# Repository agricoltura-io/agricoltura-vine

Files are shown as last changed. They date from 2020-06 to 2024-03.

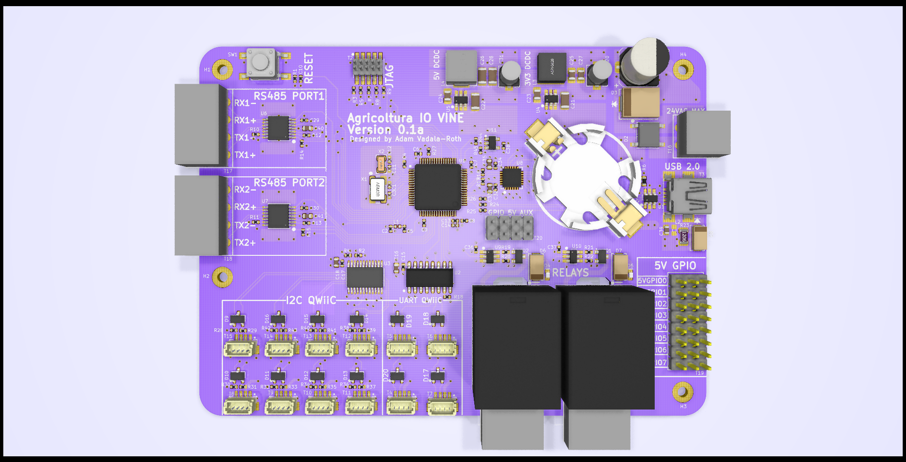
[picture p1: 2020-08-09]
PCB/agricoltura-vine/agricoltura-vineRAY.png

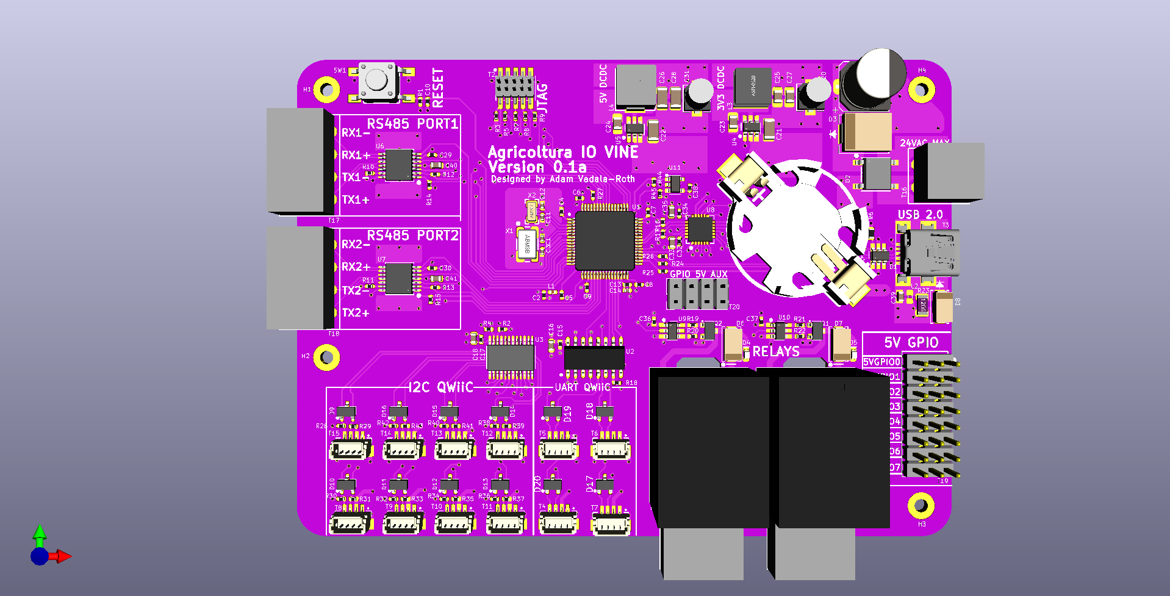
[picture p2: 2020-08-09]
PCB/agricoltura-vine/agricoltura-vine.png

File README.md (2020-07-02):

# agricoltura-vine
daisy chainable interface for a variety of sensors for various agriculture applications, this is Agricoltura-io's wired sense and control platform.

Quick Specs:
- ST Microelectronics STM32F446RET6 ARM Cortex M4F 180MHZ MCU
- 5V Tolerant Analog Inputs
- 8x I2C interfaces
- 4x UART interface (via mux)
- 8x 5V digital IO ports
- 2x G5LE-14 DC5 SPDT Relays
- USB 2.0 connectivity
- RS485 port
- 24VAC power input
- 2A 3.3V DCDC Regulator, for supporting lots of sensors
- 2A 5V DCDC Regulator, for 5V IO and other devices

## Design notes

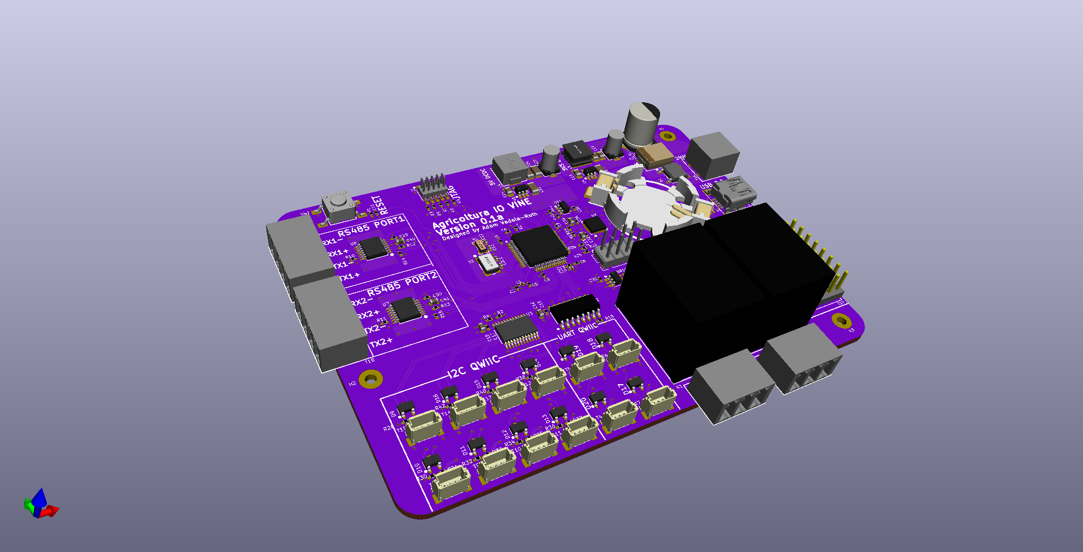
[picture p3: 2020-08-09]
PCB/agricoltura-vine/agricoltura-vineRAYAngle.png

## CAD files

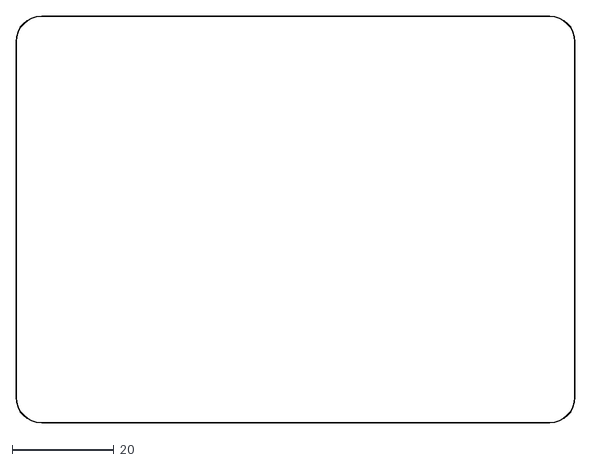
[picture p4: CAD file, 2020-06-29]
PCB/agricoltura-vine/Vine_Ivy_BRD_Shape.dxf
110.0 x 80.0

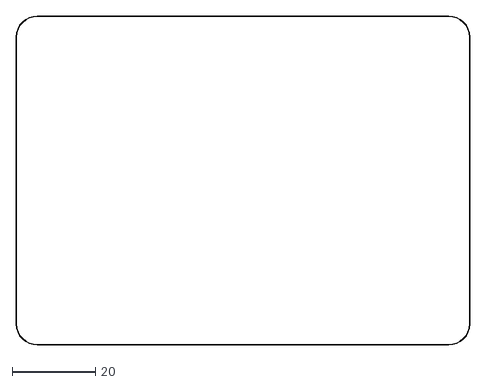
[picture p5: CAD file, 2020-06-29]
PCB/agricoltura-vine/Vine_Ivy_BRD_Margin.dxf
109.0 x 79.0

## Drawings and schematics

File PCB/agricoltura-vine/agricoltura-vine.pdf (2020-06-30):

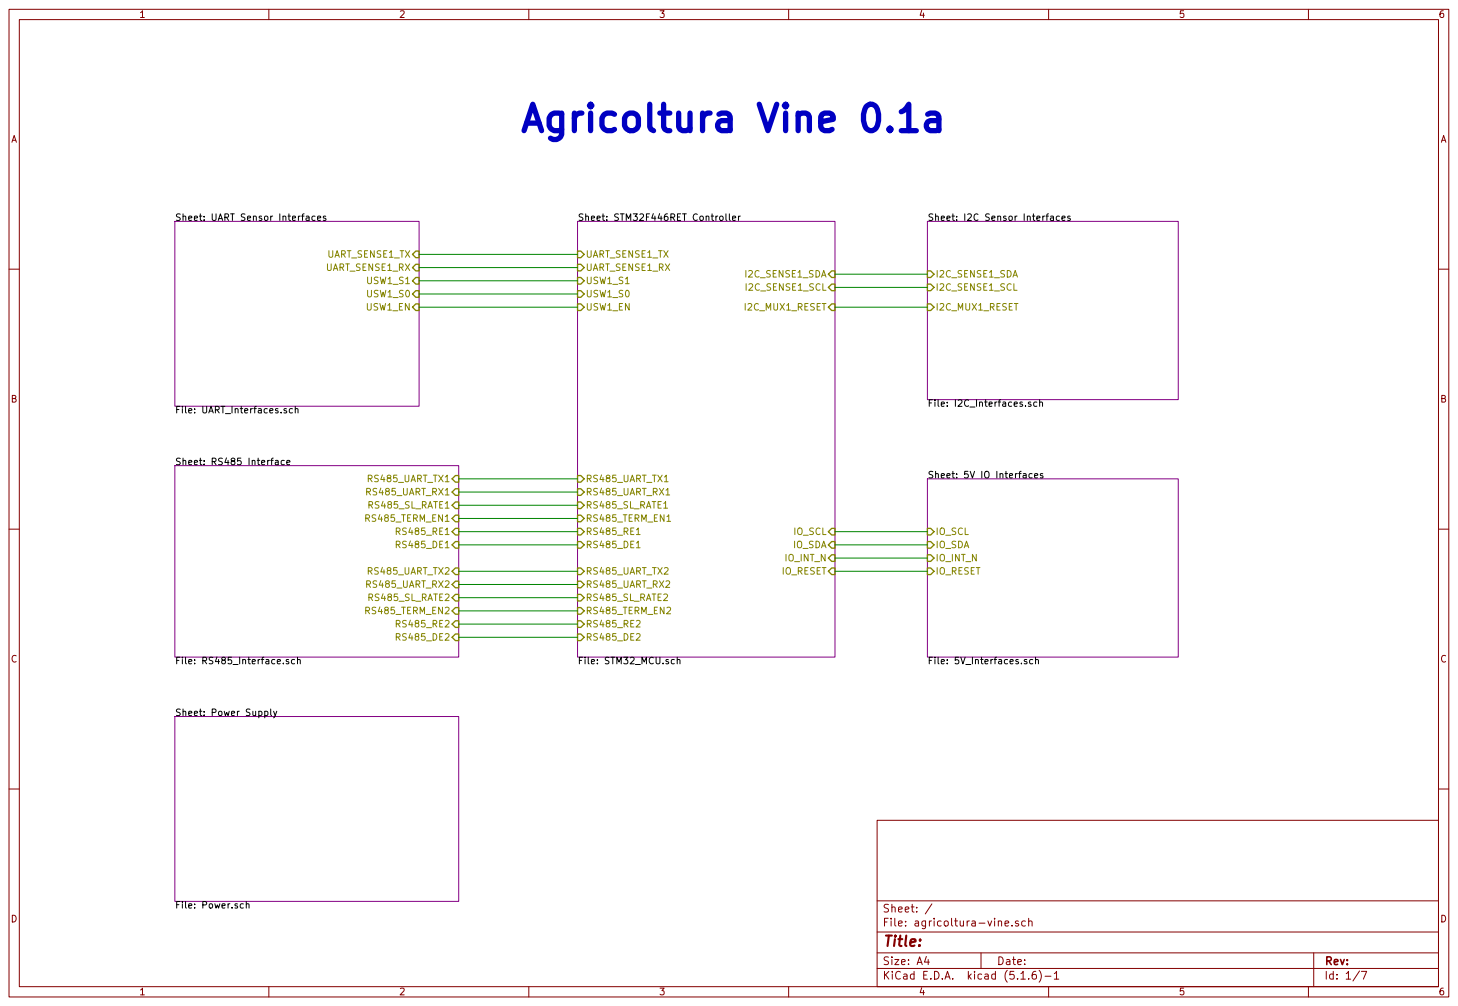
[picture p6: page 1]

IO_RESET Sheet: STM32F446RET Controller File: STM32_MCU.sch UART_SENSE1_TX RS485_UART_TX1 RS485_UART_RX1 RS485_UART_TX2 RS485_UART_RX2

Sheet: I2C Sensor Interfaces File: I2C_Interfaces.sch

Sheet: 5V IO Interfaces File: 5V_Interfaces.sch

File: agricoltura-vine.sch Sheet: /
Id: 1/7 Title:

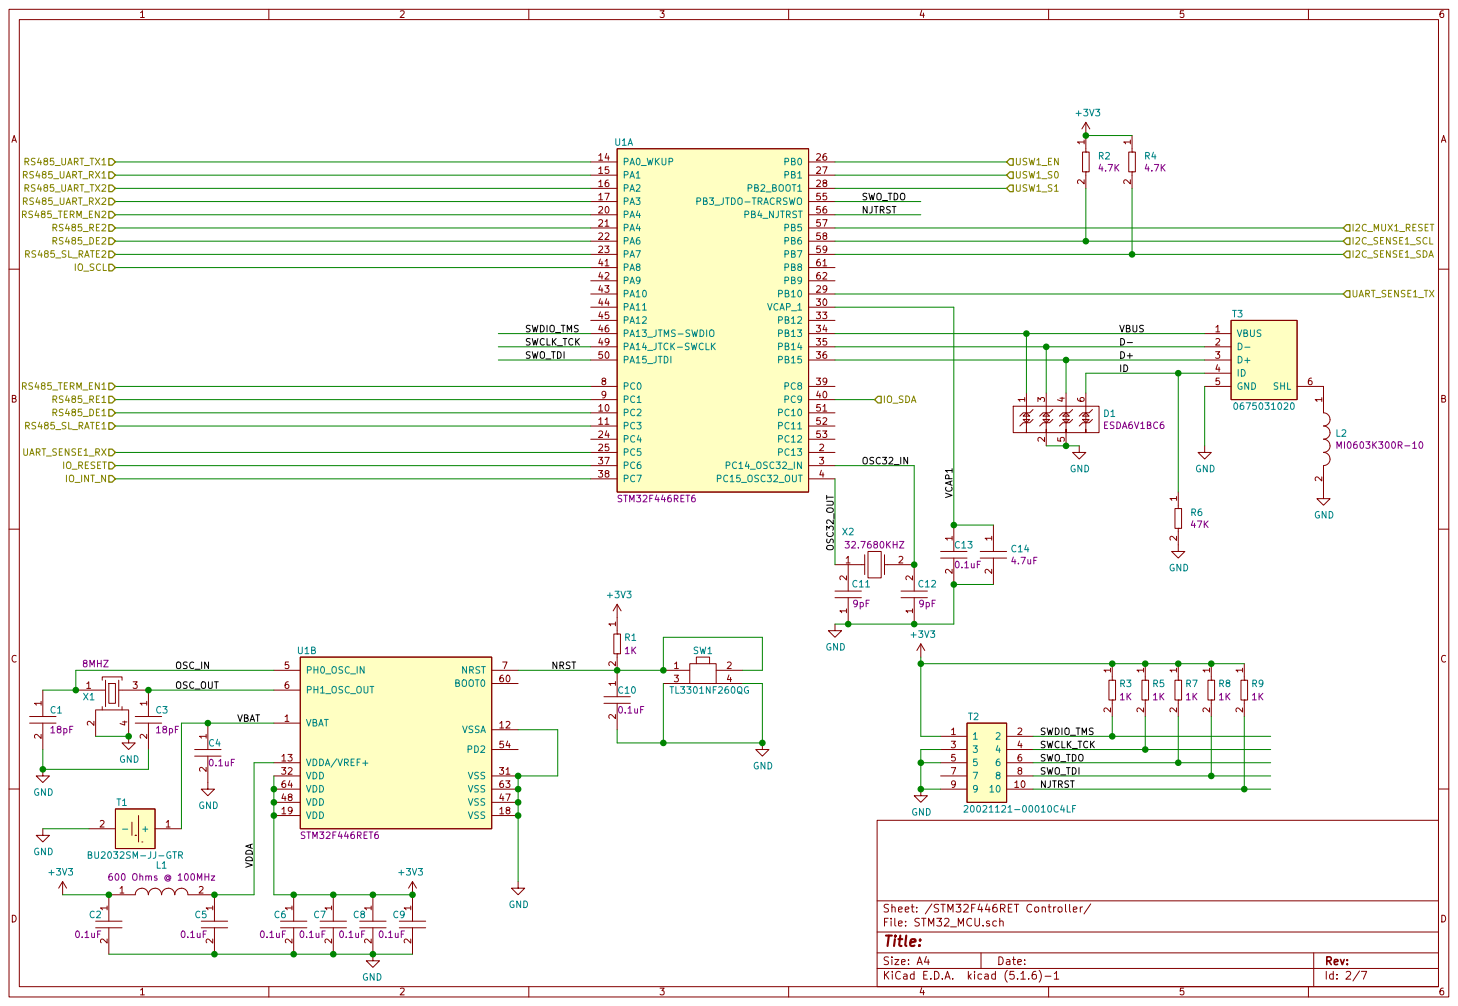
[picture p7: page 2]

File: STM32_MCU.sch Sheet: /STM32F446RET Controller/
Id: 2/7 Title:

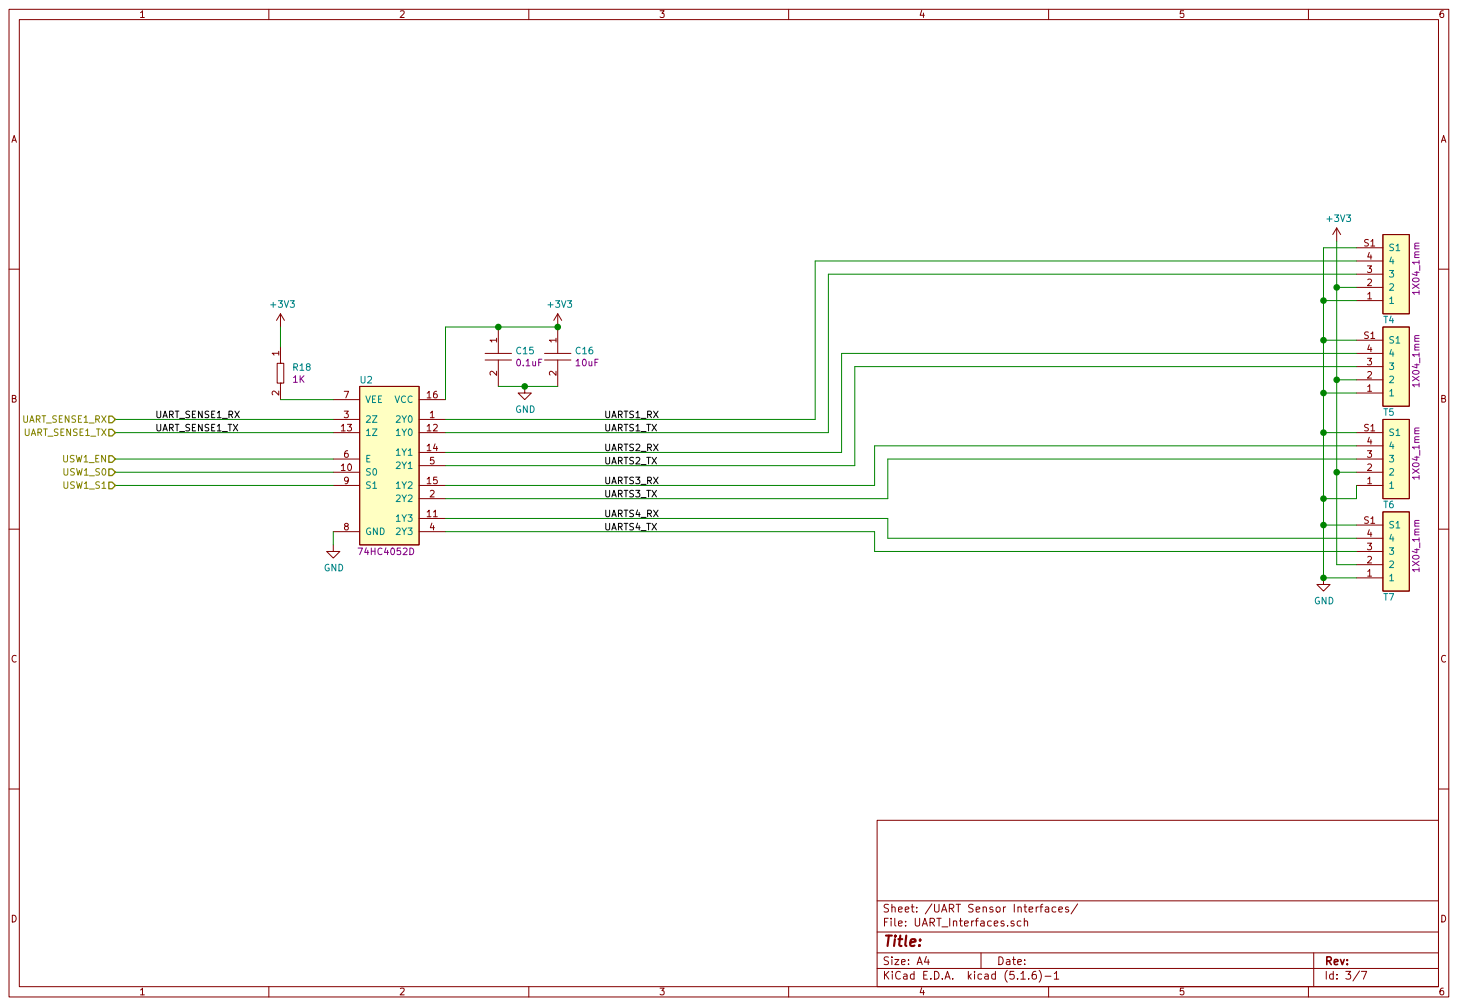
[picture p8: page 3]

File: UART_Interfaces.sch Sheet: /UART Sensor Interfaces/
Id: 3/7 Title:

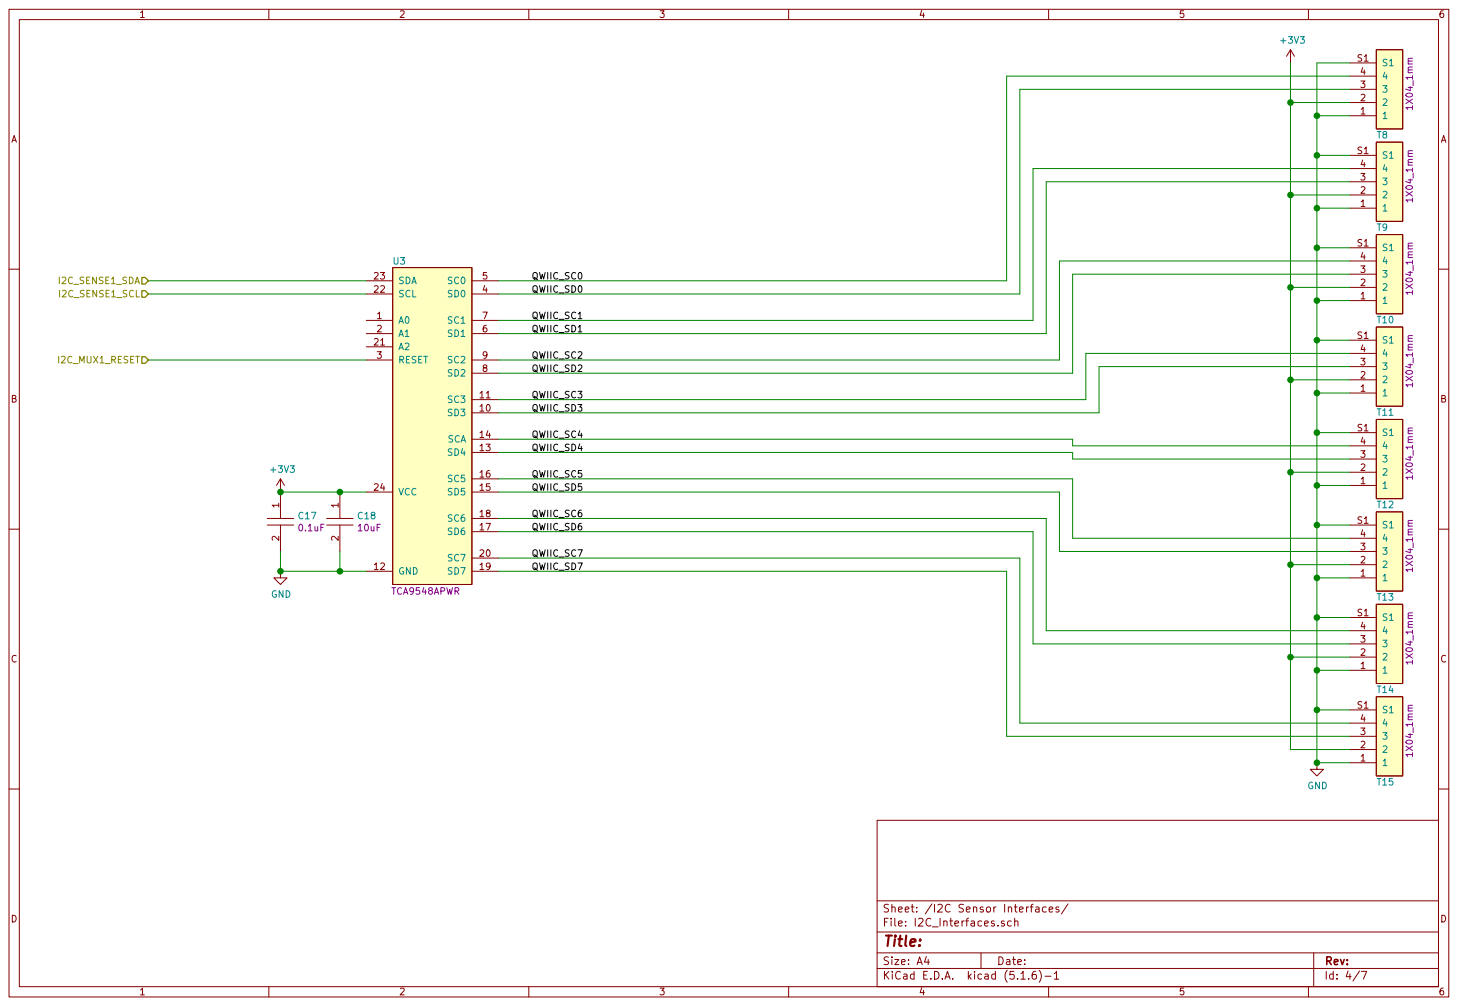
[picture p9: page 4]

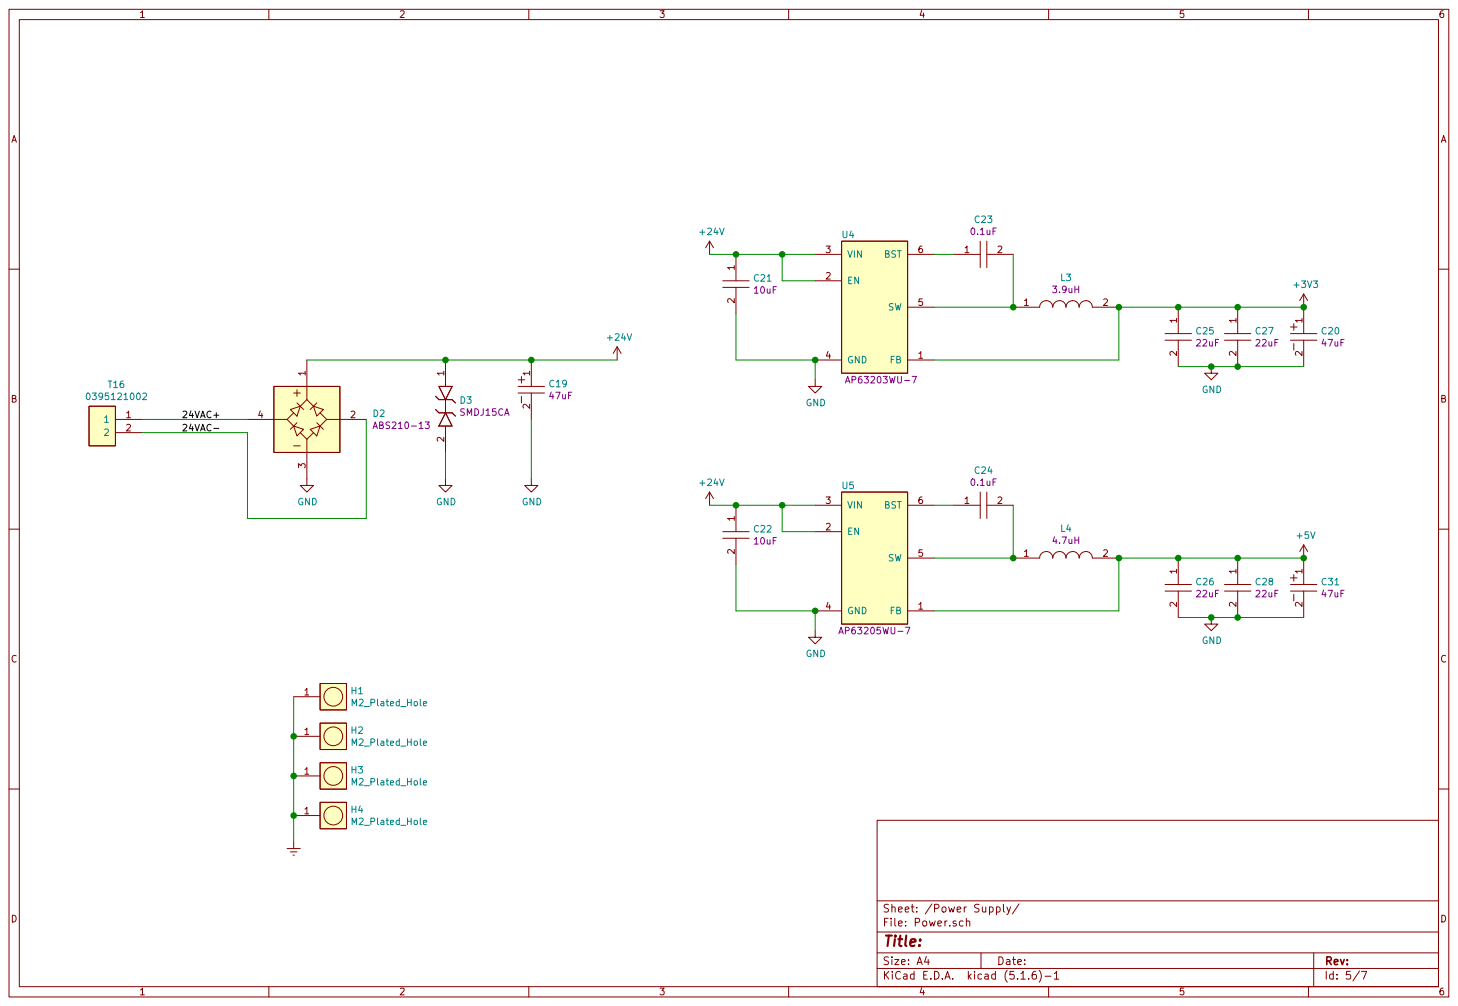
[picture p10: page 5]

Id: 5/7 Title: File: Power.sch Sheet: /Power Supply/

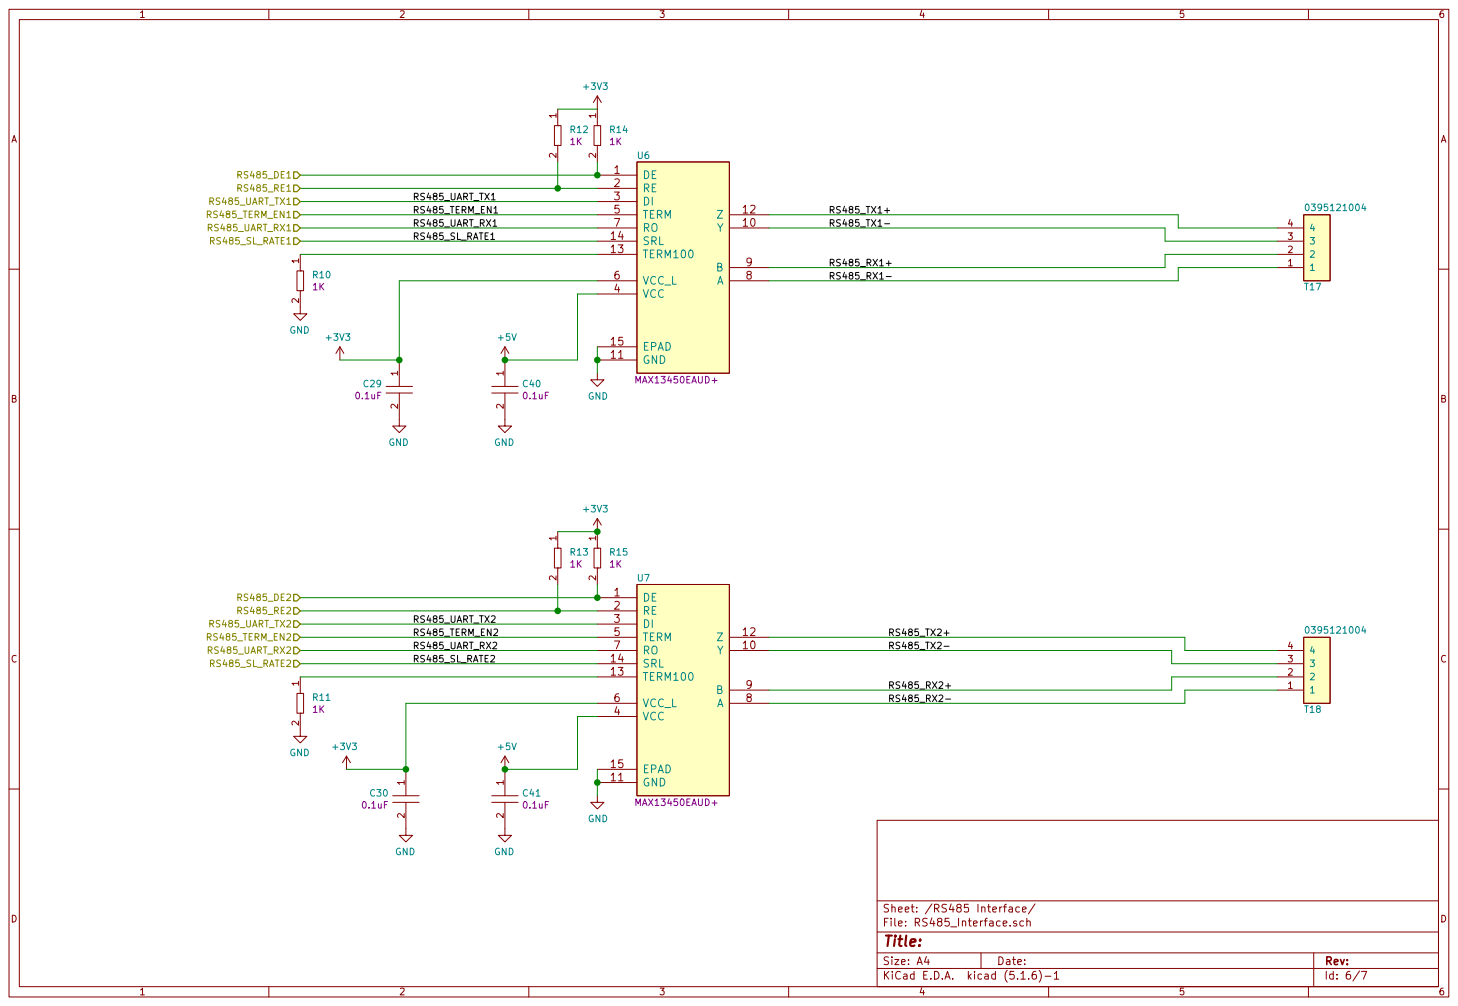
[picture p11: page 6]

File: RS485_Interface.sch Sheet: /RS485 Interface/

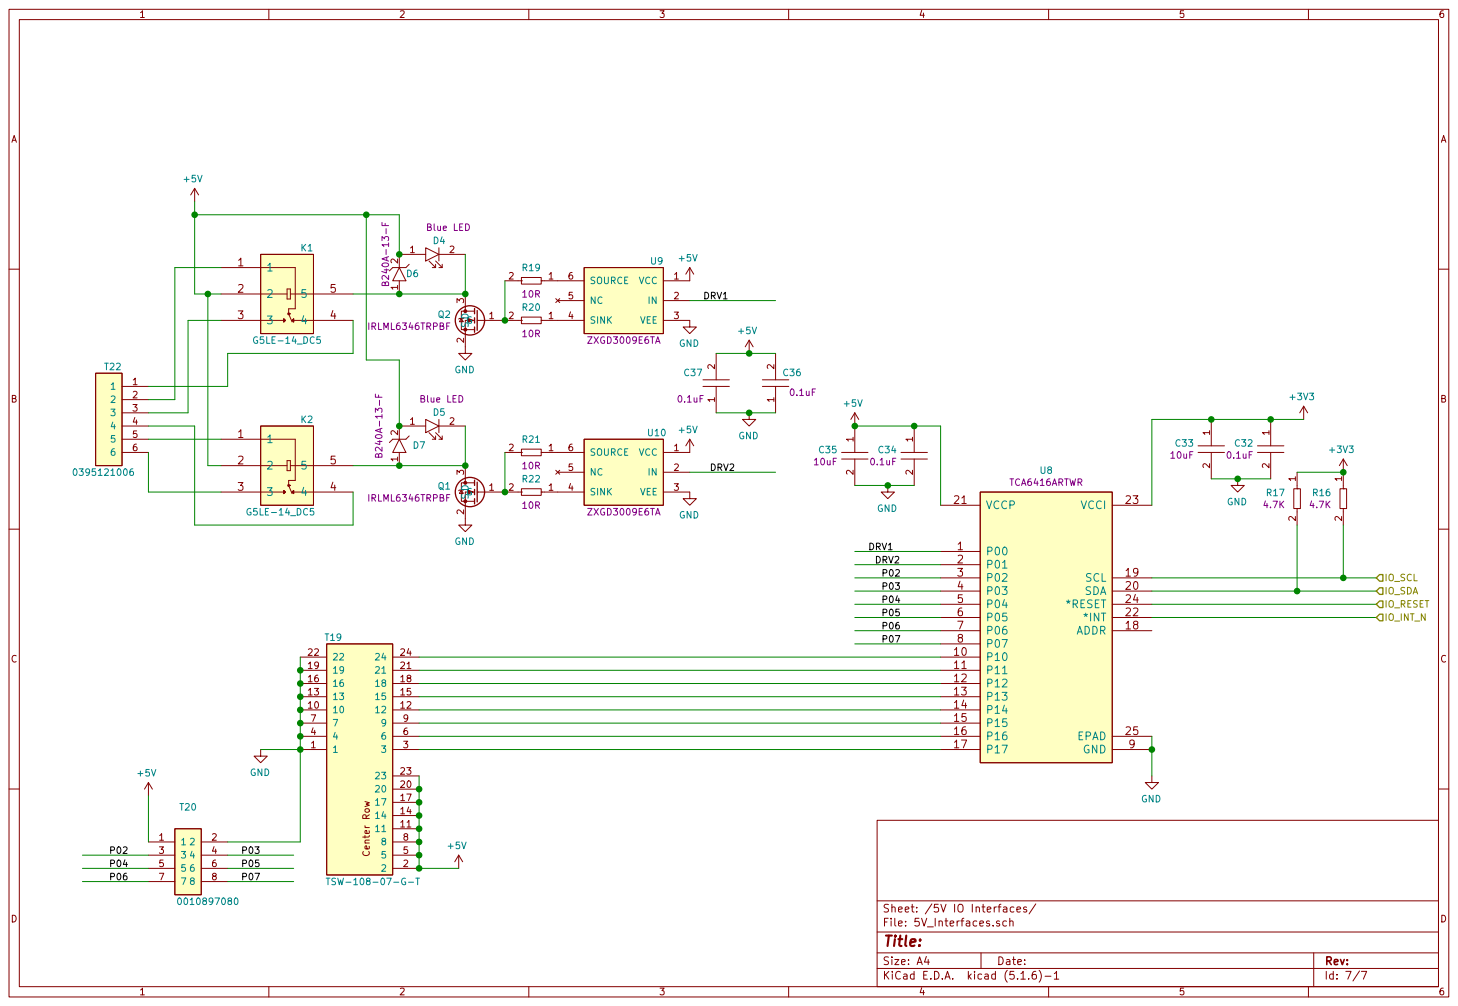
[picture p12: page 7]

File: 5V_Interfaces.sch Sheet: /5V IO Interfaces/
Id: 7/7 Title:

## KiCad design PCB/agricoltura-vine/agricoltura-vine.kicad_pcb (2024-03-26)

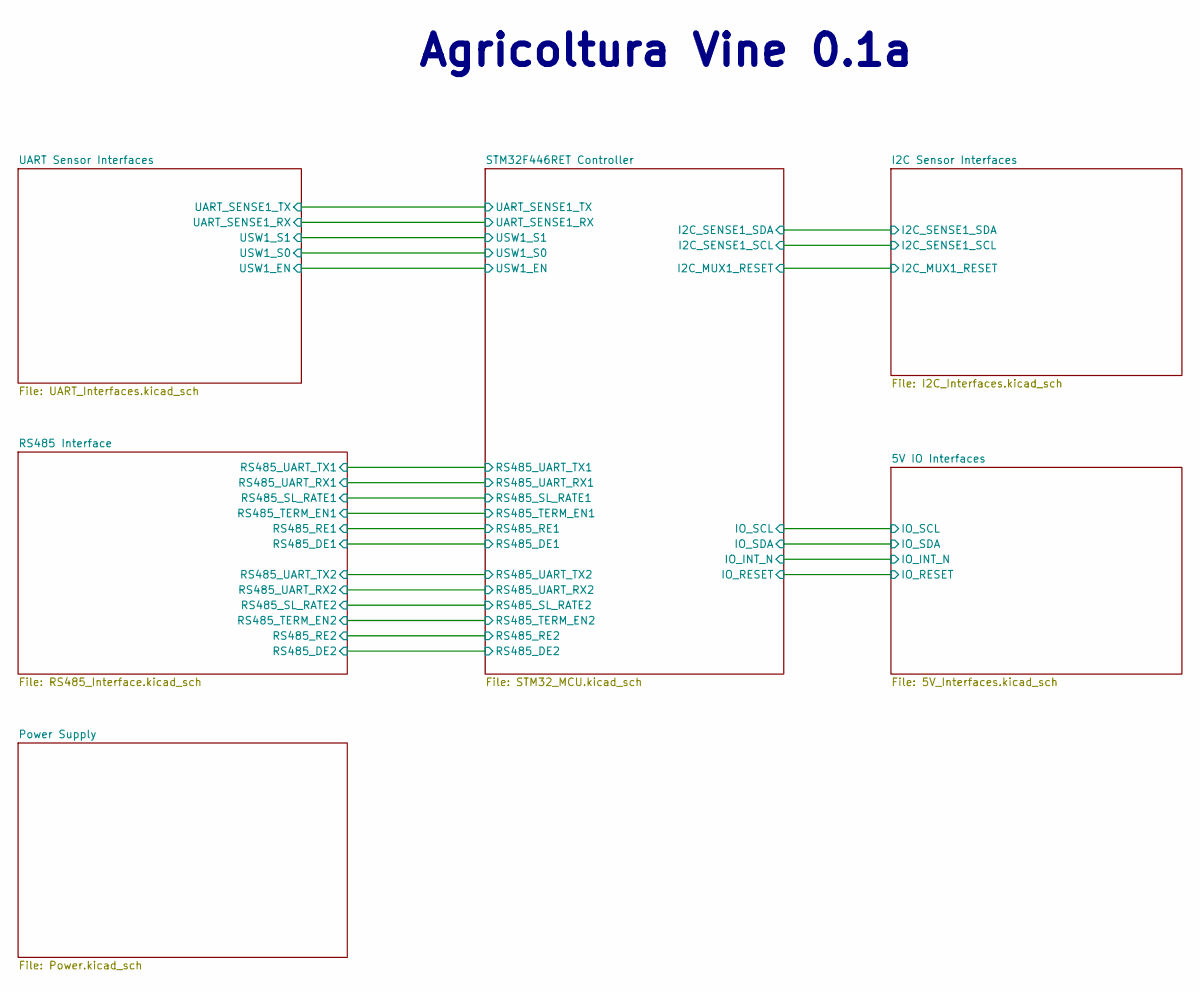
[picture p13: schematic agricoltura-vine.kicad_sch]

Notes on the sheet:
Agricoltura Vine 0.1a

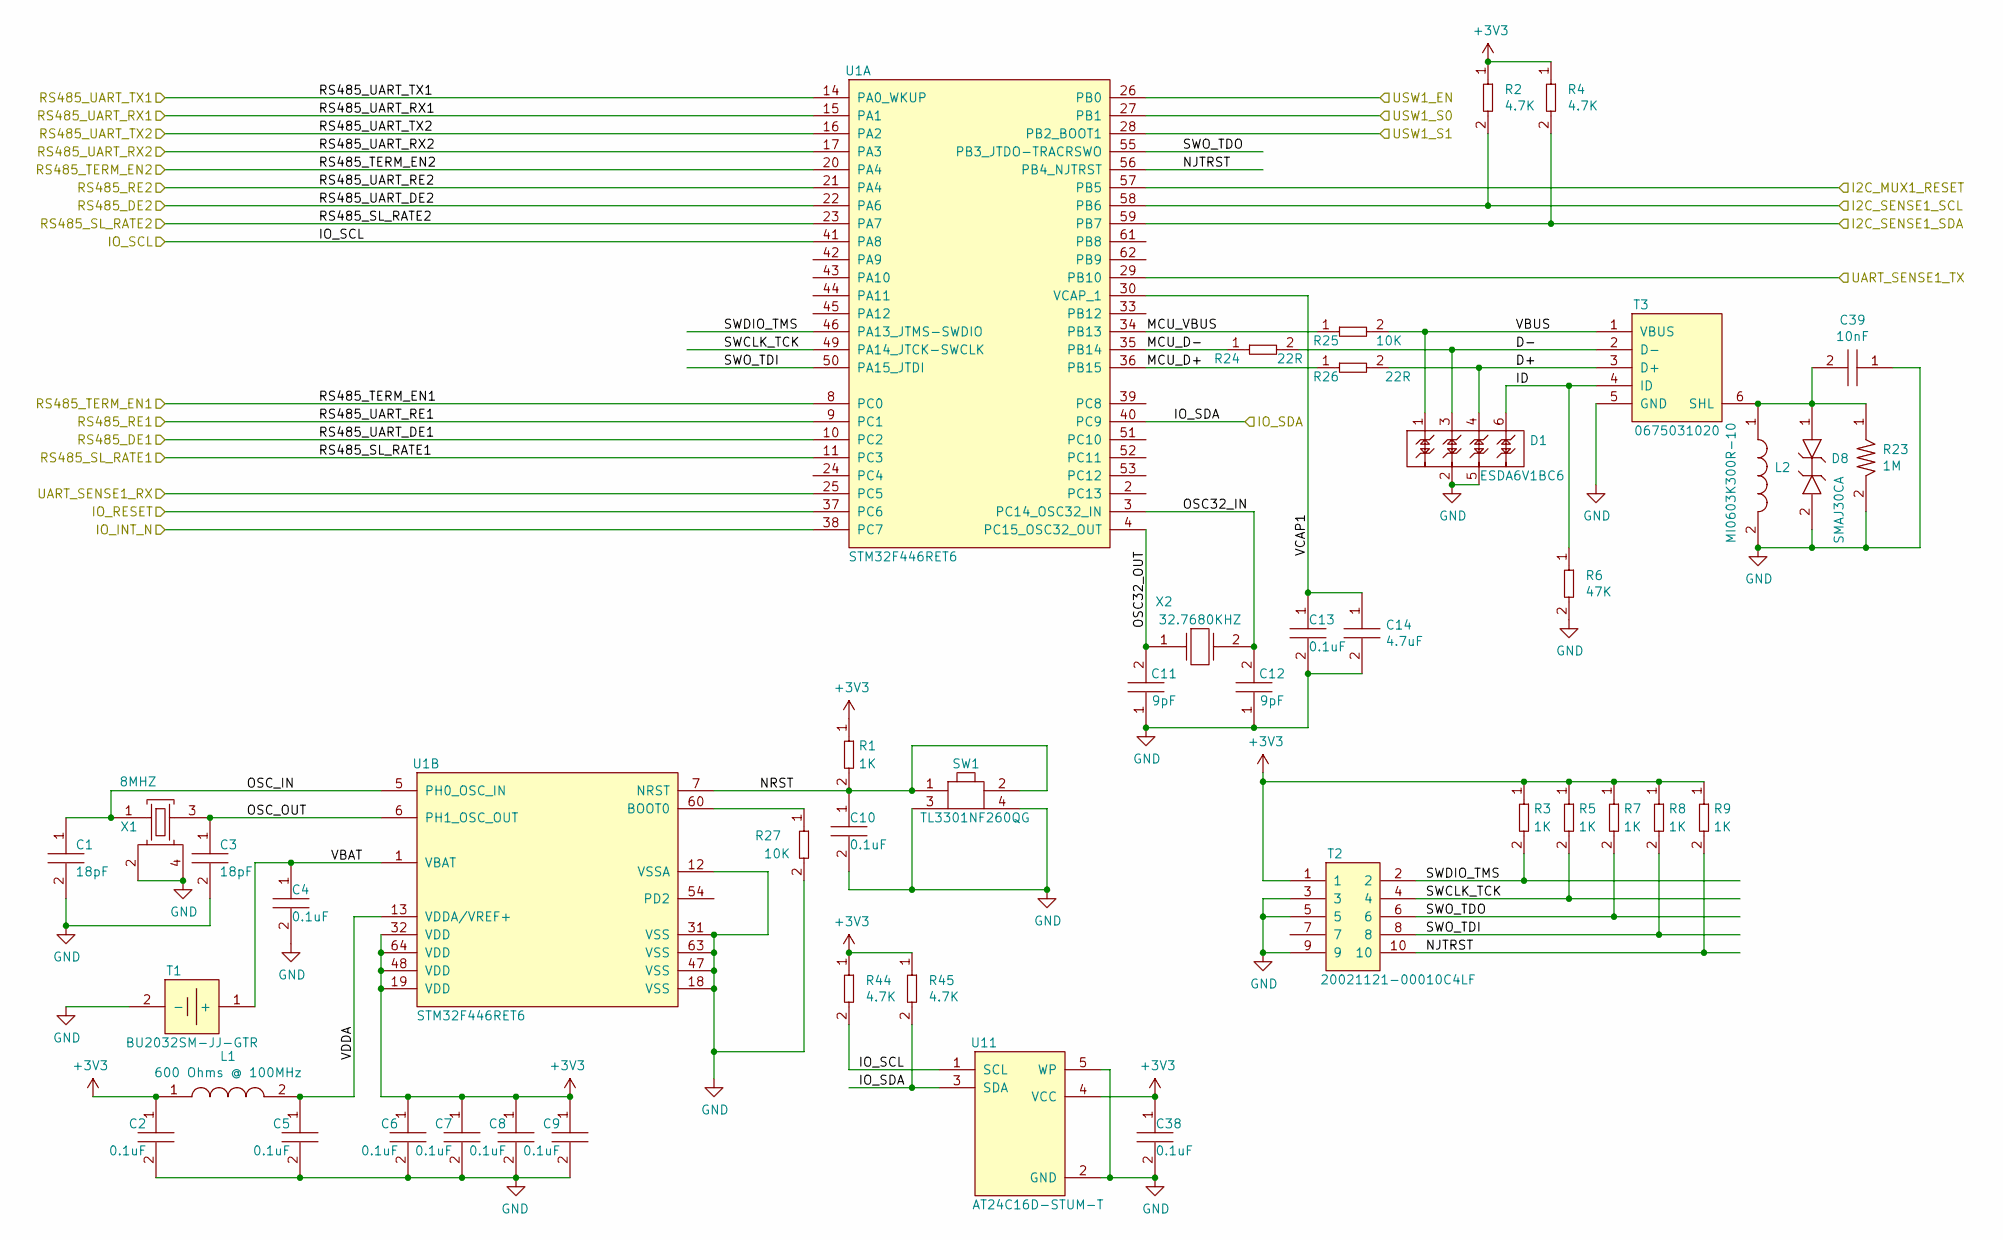
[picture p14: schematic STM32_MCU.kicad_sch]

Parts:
C1, C3: GCM1555C1H180GA16D; C0402; Tolerance 2%; Voltage 50V; MFR# GCM1555C1H180GA16D
C2, C4, C5, C6, C7, C8, C9, C10, C13, C38: C0402C104K9PACTU; R0402; Tolerance 10%; Voltage 6.3V; MFR# C0402C104K9PACTU
C11, C12: CL05C090CB5NNNC; C0402; Tolerance ±0.25pF; Voltage 50V; MFR# CL05C090CB5NNNC
C14: GRM155R60J475ME47D; C0402; Tolerance 20%; Voltage 6.3V; MFR# GRM155R60J475ME47D
C39: C0603X103K1RAC3316; C0603; Tolerance 10%; Voltage 100V; MFR# C0603X103K1RAC3316
D1: ESDA6V1BC6; SOT-23-6_Handsoldering; Tolerance *; Voltage 5V/6.1VBreakdown; MFR# ESDA6V1BC6
D8: SMAJ30CA; Tolerance *; Voltage 30V Clamp; MFR# SMAJ30CA
L1: BLM15HG601SN1D; Tolerance *; Voltage *; MFR# BLM15HG601SN1D
L2: MI0603K300R-10; Tolerance *; Voltage *; MFR# MI0603K300R-10
R1, R3, R5, R7, R8, R9: RC0402FR-071KL; R0402; Tolerance 1%; Voltage *; MFR# RC0402FR-071KL
R2, R4, R44, R45: RC0402FR-074K7L; R0402; Tolerance 1%; Voltage *; MFR# RC0402FR-074K7L
R6: RC0603FR-0747KL; R0603; Tolerance 1%; Voltage *; MFR# RC0603FR-0747KL
R23: RC1206FR-071ML; R1206; Tolerance 1%; Voltage *; MFR# RC1206FR-071ML
R24, R26: RC0402FR-0722RL; R0402; Tolerance 1%; Voltage *; MFR# RC0402FR-0722RL
R25, R27: RC0402FR-0710KL; R0402; Tolerance 1%; Voltage *; MFR# RC0402FR-0710KL
SW1: TL3301NF260QG; Tolerance *; Voltage 12VDC; MFR# TL3301NF260QG
T1: BU2032SM-JJ-GTR; Tolerance *; Voltage 3.3V; MFR# BU2032SM-JJ-GTR
T2: 20021121-00010C4LF; Tolerance *; Voltage *; MFR# 20021121-00010C4LF
T3: 0675031020; USB_Mini-B; Tolerance *; Voltage 5V; MFR# 0675031020
U1: STM32F446RET6; Tolerance *; Voltage 1.7V ~ 3.6V; MFR# STM32F446RET6
U11: AT24C16D-STUM-T; SOT-23-5; Tolerance *; Voltage 3.3V; MFR# AT24C16D-STUM-T
X1: ABM3B-8.000MHZ-B2-T; ABM3B8.000MHZB2T; Tolerance *; Voltage *; MFR# ABM3B-8.000MHZ-B2-T
X2: ABS07-32.768KHZ-9-T; Tolerance *; Voltage *; MFR# ABS07-32.768KHZ-9-T

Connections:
+3V3: C2.1, C6.1, C7.1, C8.1, C9.1, C38.1, L1.1, R1.1, R2.1, R3.1, R4.1, R5.1, R7.1, R8.1, R9.1, R44.1, R45.1, T2.1, U1.19 (VDD), U1.32 (VDD), U1.48 (VDD), U1.64 (VDD), U11.4 (VCC); also elsewhere on the board
/5V IO Interfaces/IO_INT_N: U1.38 (PC7); also elsewhere on the board
/5V IO Interfaces/IO_RESET: U1.37 (PC6); also elsewhere on the board
/5V IO Interfaces/IO_SCL: R44.2, U1.41 (PA8), U11.1 (SCL); also elsewhere on the board
/5V IO Interfaces/IO_SDA: R45.2, U1.40 (PC9), U11.3 (SDA); also elsewhere on the board
/I2C Sensor Interfaces/I2C_MUX1_RESET: U1.57 (PB5); also elsewhere on the board
/I2C Sensor Interfaces/I2C_SENSE1_SCL: R2.2, U1.58 (PB6); also elsewhere on the board
/I2C Sensor Interfaces/I2C_SENSE1_SDA: R4.2, U1.59 (PB7); also elsewhere on the board
/RS485 Interface/RS485_DE1: U1.10 (PC2); also elsewhere on the board
/RS485 Interface/RS485_DE2: U1.22 (PA6); also elsewhere on the board
/RS485 Interface/RS485_RE1: U1.9 (PC1); also elsewhere on the board
/RS485 Interface/RS485_RE2: U1.21 (PA4); also elsewhere on the board
/RS485 Interface/RS485_SL_RATE1: U1.11 (PC3); also elsewhere on the board
/RS485 Interface/RS485_SL_RATE2: U1.23 (PA7); also elsewhere on the board
/RS485 Interface/RS485_TERM_EN1: U1.8 (PC0); also elsewhere on the board
/RS485 Interface/RS485_TERM_EN2: U1.20 (PA4); also elsewhere on the board
/RS485 Interface/RS485_UART_RX1: U1.15 (PA1); also elsewhere on the board
/RS485 Interface/RS485_UART_RX2: U1.17 (PA3); also elsewhere on the board
/RS485 Interface/RS485_UART_TX1: U1.14 (PA0_WKUP); also elsewhere on the board
/RS485 Interface/RS485_UART_TX2: U1.16 (PA2); also elsewhere on the board
/STM32F446RET Controller/D+: D1.4, R26.2, T3.3 (D+)
/STM32F446RET Controller/D-: D1.3, R24.2, T3.2 (D-)
/STM32F446RET Controller/ID: D1.6, R6.1, T3.4 (ID)
/STM32F446RET Controller/MCU_D+: R26.1, U1.36 (PB15)
/STM32F446RET Controller/MCU_D-: R24.1, U1.35 (PB14)
/STM32F446RET Controller/MCU_VBUS: R25.1, U1.34 (PB13)
/STM32F446RET Controller/NJTRST: R9.2, T2.10, U1.56 (PB4_NJTRST)
/STM32F446RET Controller/NRST: C10.1, R1.2, SW1.1, SW1.2, U1.7 (NRST)
/STM32F446RET Controller/OSC32_IN: C12.2, U1.3 (PC14_OSC32_IN), X2.2
/STM32F446RET Controller/OSC32_OUT: C11.2, U1.4 (PC15_OSC32_OUT), X2.1
/STM32F446RET Controller/OSC_IN: C1.1, U1.5 (PH0_OSC_IN), X1.1
/STM32F446RET Controller/OSC_OUT: C3.1, U1.6 (PH1_OSC_OUT), X1.3
/STM32F446RET Controller/SWCLK_TCK: R5.2, T2.4, U1.49 (PA14_JTCK-SWCLK)
/STM32F446RET Controller/SWDIO_TMS: R3.2, T2.2, U1.46 (PA13_JTMS-SWDIO)
/STM32F446RET Controller/SWO_TDI: R8.2, T2.8, U1.50 (PA15_JTDI)
/STM32F446RET Controller/SWO_TDO: R7.2, T2.6, U1.55 (PB3_JTDO-TRACRSWO)
/STM32F446RET Controller/UART_SENSE1_RX: U1.25 (PC5); also elsewhere on the board
/STM32F446RET Controller/UART_SENSE1_TX: U1.29 (PB10); also elsewhere on the board
/STM32F446RET Controller/USW1_EN: U1.26 (PB0); also elsewhere on the board
/STM32F446RET Controller/USW1_S0: U1.27 (PB1); also elsewhere on the board
/STM32F446RET Controller/USW1_S1: U1.28 (PB2_BOOT1); also elsewhere on the board
/STM32F446RET Controller/VBAT: C4.1, T1.1 (+), U1.1 (VBAT)
/STM32F446RET Controller/VBUS: D1.1, R25.2, T3.1 (VBUS)
/STM32F446RET Controller/VCAP1: C13.1, C14.1, U1.30 (VCAP_1)
/STM32F446RET Controller/VDDA: C5.1, L1.2, U1.13 (VDDA/VREF+)
GND: C1.2, C2.2, C3.2, C4.2, C5.2, C6.2, C7.2, C8.2, C9.2, C10.2, C11.1, C12.1, C13.2, C14.2, C38.2, C39.1, D1.2, D1.5, D8.2, L2.2, R6.2, R23.2, R27.2, SW1.3, SW1.4, T1.2 (-), T2.3, T2.5, T2.9, T3.5 (GND), U1.12 (VSSA), U1.18 (VSS), U1.31 (VSS), U1.47 (VSS), U1.63 (VSS), U11.2 (GND), U11.5 (WP), X1.2, X1.4; also elsewhere on the board
unnamed: C39.2, D8.1, L2.1, R23.1, T3.6 (SHL)
unnamed: R27.1, U1.60 (BOOT0)

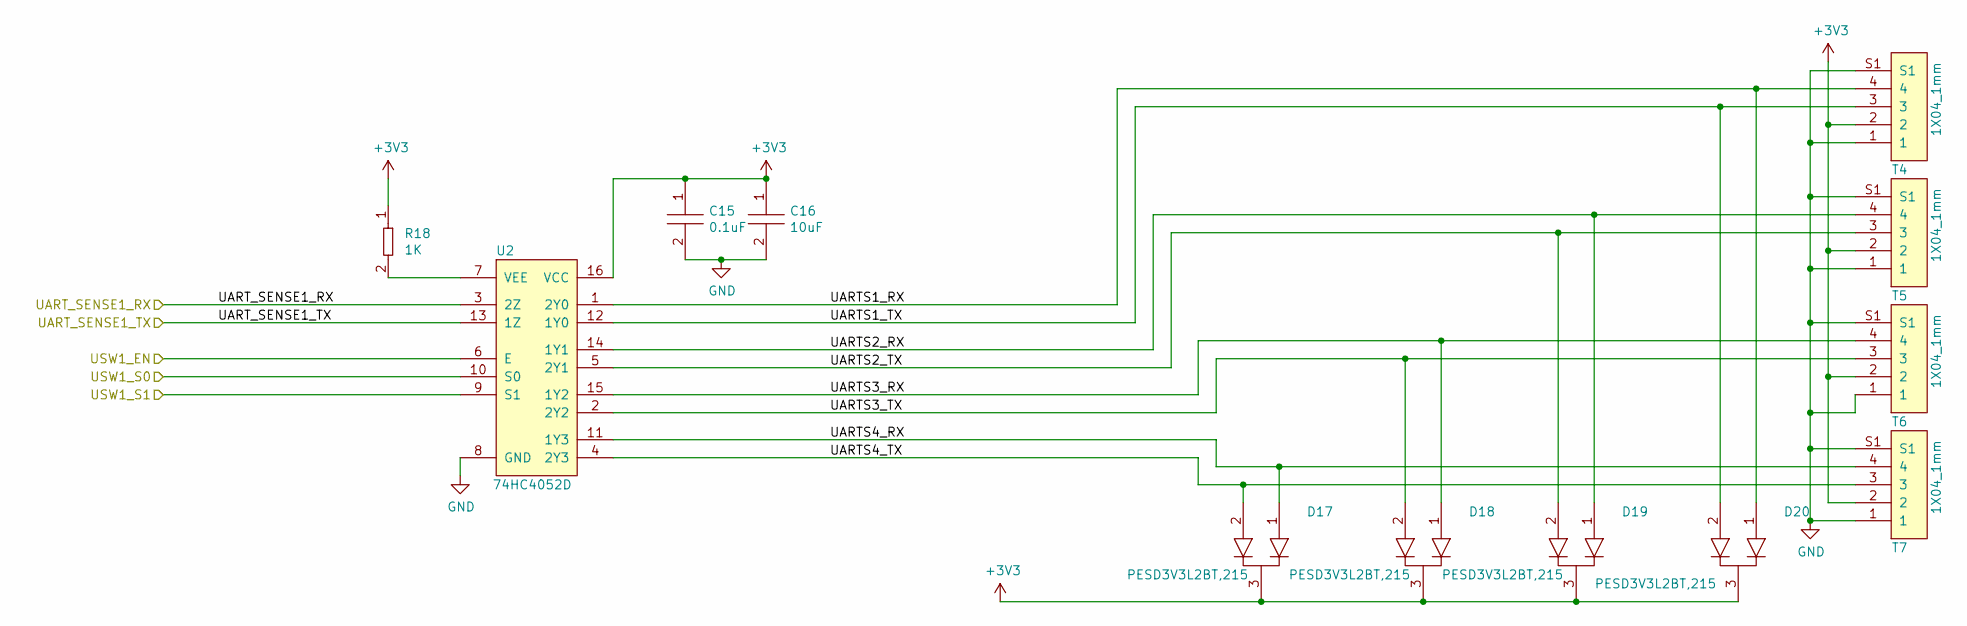
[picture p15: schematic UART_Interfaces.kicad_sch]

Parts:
C15: C0402C104K9PACTU; R0402; Tolerance 10%; Voltage 6.3V; MFR# C0402C104K9PACTU
C16: GRM188R61A106KE69J; C0603; Tolerance 10%; Voltage 10V; MFR# GRM188R61A106KE69J
D17, D18, D19, D20: PESD3V3L2BT,215; SOT-23; Tolerance *; Voltage *; MFR# PESD3V3L2BT,215
R18: RC0402FR-071KL; R0402; Tolerance 1%; Voltage *; MFR# RC0402FR-071KL
T4, T5, T6, T7: BM04B-SRSS-TB(LF)(SN); CONN_BM04B-SRSS-TB(LF)(SN); Tolerance *; Voltage 50V; MFR# BM04B-SRSS-TB(LF)(SN)
U2: 74HC4052D; Tolerance *; Voltage 2V ~ 6V; MFR# 74HC4052D

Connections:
+3V3: C15.1, C16.1, D17.3, D18.3, D19.3, D20.3, R18.1, T4.2, T5.2, T6.2, T7.2, U2.16 (VCC); also elsewhere on the board
/STM32F446RET Controller/UART_SENSE1_RX: U2.3 (2Z); also elsewhere on the board
/STM32F446RET Controller/UART_SENSE1_TX: U2.13 (1Z); also elsewhere on the board
/STM32F446RET Controller/USW1_EN: U2.6 (E); also elsewhere on the board
/STM32F446RET Controller/USW1_S0: U2.10 (S0); also elsewhere on the board
/STM32F446RET Controller/USW1_S1: U2.9 (S1); also elsewhere on the board
/UART Sensor Interfaces/UARTS1_RX: D20.1, T4.4, U2.1 (2Y0)
/UART Sensor Interfaces/UARTS1_TX: D20.2, T4.3, U2.12 (1Y0)
/UART Sensor Interfaces/UARTS2_RX: D19.1, T5.4, U2.14 (1Y1)
/UART Sensor Interfaces/UARTS2_TX: D19.2, T5.3, U2.5 (2Y1)
/UART Sensor Interfaces/UARTS3_RX: D18.1, T6.4, U2.15 (1Y2)
/UART Sensor Interfaces/UARTS3_TX: D18.2, T6.3, U2.2 (2Y2)
/UART Sensor Interfaces/UARTS4_RX: D17.1, T7.4, U2.11 (1Y3)
/UART Sensor Interfaces/UARTS4_TX: D17.2, T7.3, U2.4 (2Y3)
GND: C15.2, C16.2, T4.1, T4.S1, T5.1, T5.S1, T6.1, T6.S1, T7.1, T7.S1, U2.8 (GND); also elsewhere on the board
unnamed: R18.2, U2.7 (VEE)

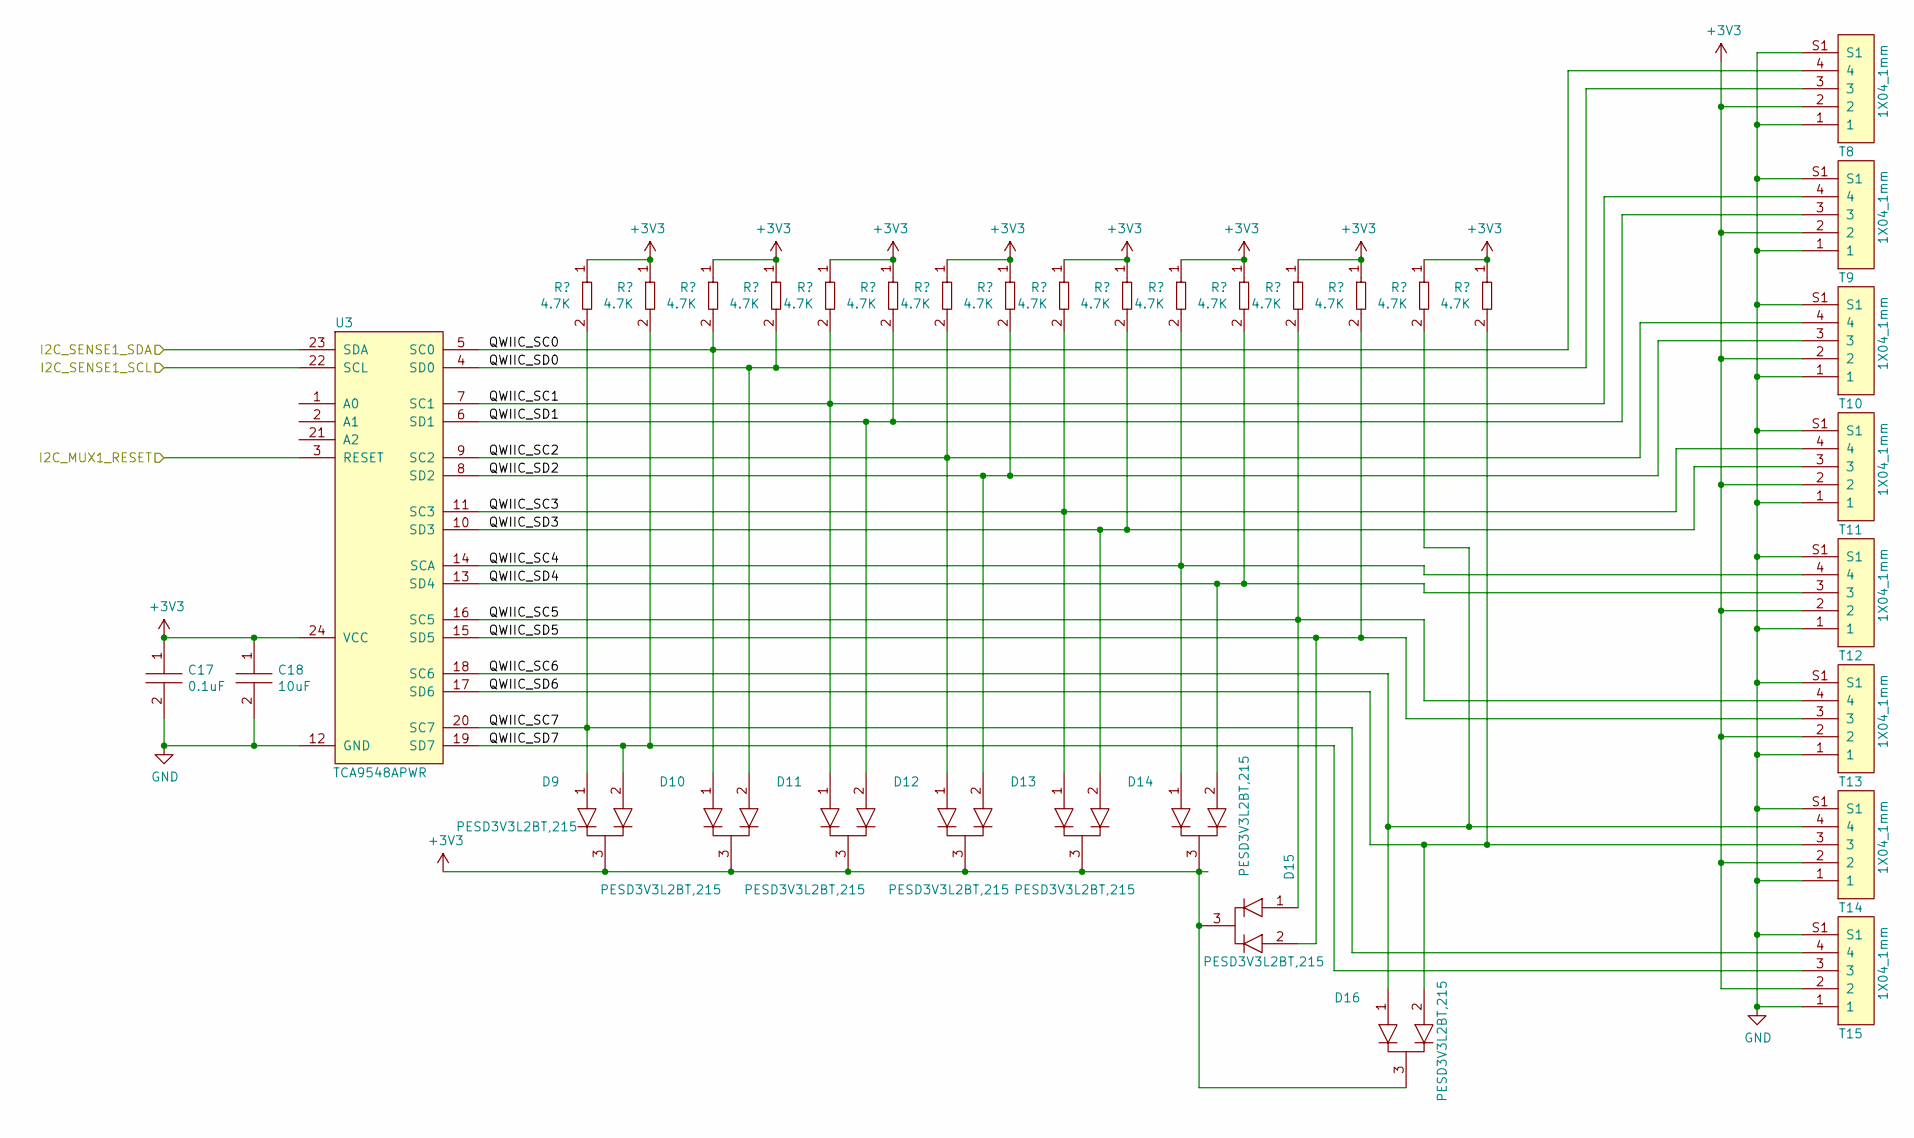
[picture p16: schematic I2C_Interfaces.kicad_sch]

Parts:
C17: C0402C104K9PACTU; R0402; Tolerance 10%; Voltage 6.3V; MFR# C0402C104K9PACTU
C18: GRM188R61A106KE69J; C0603; Tolerance 10%; Voltage 10V; MFR# GRM188R61A106KE69J
D9, D10, D11, D12, D13, D14, D15, D16: PESD3V3L2BT,215; SOT-23; Tolerance *; Voltage *; MFR# PESD3V3L2BT,215
R28, R29, R30, R31, R32, R33, R34, R35, R36, R37, R38, R39, R40, R41, R42, R43: RC0402FR-074K7L; R0402; Tolerance 1%; Voltage *; MFR# RC0402FR-074K7L
T8, T9, T10, T11, T12, T13, T14, T15: BM04B-SRSS-TB(LF)(SN); CONN_BM04B-SRSS-TB(LF)(SN); Tolerance *; Voltage 50V; MFR# BM04B-SRSS-TB(LF)(SN)
U3: TCA9548APWR; Tolerance *; Voltage 1.65V ~ 5.5V; MFR# TCA9548APWR

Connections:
+3V3: C17.1, C18.1, D9.3, D10.3, D11.3, D12.3, D13.3, D14.3, D15.3, D16.3, R28.1, R29.1, R30.1, R31.1, R32.1, R33.1, R34.1, R35.1, R36.1, R37.1, R38.1, R39.1, R40.1, R41.1, R42.1, R43.1, T8.2, T9.2, T10.2, T11.2, T12.2, T13.2, T14.2, T15.2, U3.24 (VCC); also elsewhere on the board
/I2C Sensor Interfaces/I2C_MUX1_RESET: U3.3 (RESET); also elsewhere on the board
/I2C Sensor Interfaces/I2C_SENSE1_SCL: U3.22 (SCL); also elsewhere on the board
/I2C Sensor Interfaces/I2C_SENSE1_SDA: U3.23 (SDA); also elsewhere on the board
/I2C Sensor Interfaces/QWIIC_SC0: D10.1, R30.2, T8.4, U3.5 (SC0)
/I2C Sensor Interfaces/QWIIC_SC1: D11.1, R32.2, T9.4, U3.7 (SC1)
/I2C Sensor Interfaces/QWIIC_SC2: D12.1, R34.2, T10.4, U3.9 (SC2)
/I2C Sensor Interfaces/QWIIC_SC3: D13.1, R36.2, T11.4, U3.11 (SC3)
/I2C Sensor Interfaces/QWIIC_SC4: D14.1, R38.2, T12.4, U3.14 (SCA)
/I2C Sensor Interfaces/QWIIC_SC5: D15.1, R40.2, T13.4, U3.16 (SC5)
/I2C Sensor Interfaces/QWIIC_SC6: D16.1, R42.2, T14.4, U3.18 (SC6)
/I2C Sensor Interfaces/QWIIC_SC7: D9.1, R28.2, T15.4, U3.20 (SC7)
/I2C Sensor Interfaces/QWIIC_SD0: D10.2, R31.2, T8.3, U3.4 (SD0)
/I2C Sensor Interfaces/QWIIC_SD1: D11.2, R33.2, T9.3, U3.6 (SD1)
/I2C Sensor Interfaces/QWIIC_SD2: D12.2, R35.2, T10.3, U3.8 (SD2)
/I2C Sensor Interfaces/QWIIC_SD3: D13.2, R37.2, T11.3, U3.10 (SD3)
/I2C Sensor Interfaces/QWIIC_SD4: D14.2, R39.2, T12.3, U3.13 (SD4)
/I2C Sensor Interfaces/QWIIC_SD5: D15.2, R41.2, T13.3, U3.15 (SD5)
/I2C Sensor Interfaces/QWIIC_SD6: D16.2, R43.2, T14.3, U3.17 (SD6)
/I2C Sensor Interfaces/QWIIC_SD7: D9.2, R29.2, T15.3, U3.19 (SD7)
GND: C17.2, C18.2, T8.1, T8.S1, T9.1, T9.S1, T10.1, T10.S1, T11.1, T11.S1, T12.1, T12.S1, T13.1, T13.S1, T14.1, T14.S1, T15.1, T15.S1, U3.12 (GND); also elsewhere on the board

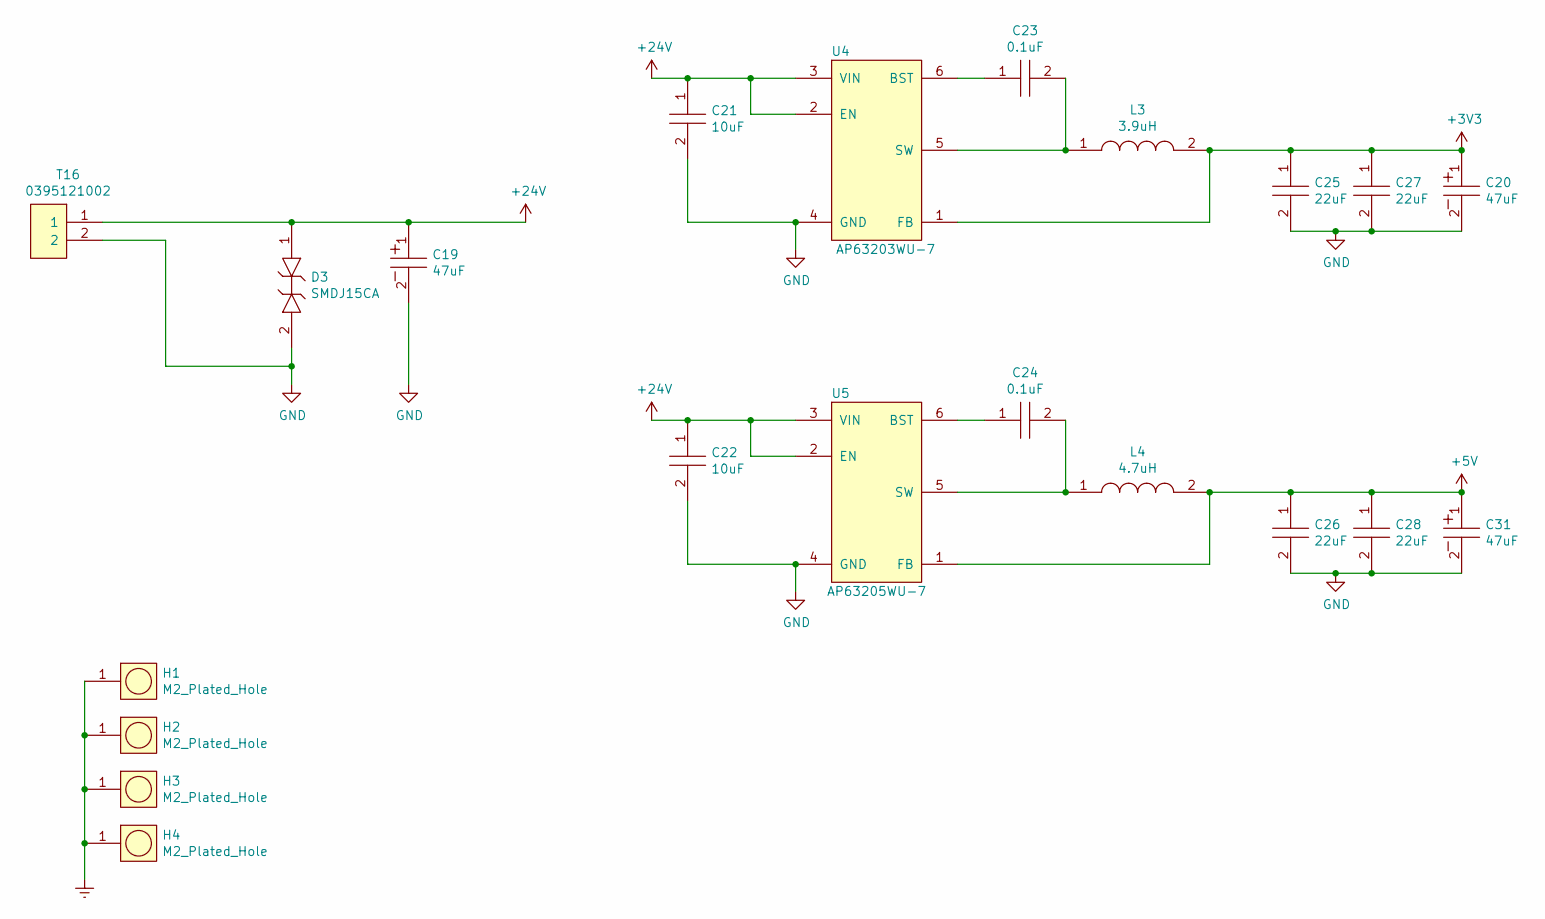
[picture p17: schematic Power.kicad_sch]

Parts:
C19: UUQ1H470MCL1GS; CP_Elec_8x10; Tolerance 20%; Voltage 50V; MFR# UUQ1H470MCL1GS
C20, C31: UCM1C470MCL1GS; Tolerance 20%; Voltage 16V; MFR# UCM1C470MCL1GS
C21, C22: GRT31CR61H106KE01L; C1206; Tolerance 10%; Voltage 50V; MFR# GRT31CR61H106KE01L
C23: C0805C104M5RACTU; C0805; Tolerance 20%; Voltage 50V; MFR# C0805C104M5RACTU
C24: C2012X7R2A104K125AA; C0805; Tolerance 10%; Voltage 100V; MFR# C2012X7R2A104K125AA
C25, C27: GRM21BD70J226ME44L; C0805; Tolerance 20%; Voltage 6.3v; MFR# GRM21BD70J226ME44L
C26, C28: GRT31CC81C226KE01L; C1206; Tolerance 10%; Voltage 16V; MFR# GRT31CC81C226KE01L
D3: SMDJ15CA; Tolerance *; Voltage 24V Clamp; MFR# SMDJ15CA
H1, H2, H3, H4: M2_Plated_Hole; M2_HOLE; Tolerance *; Voltage *; MFR# *
L3: ASPI-0628-3R9M-T1; Tolerance 20%; Voltage *; MFR# ASPI-0628-3R9M-T1
L4: SRP6540-4R7M; Tolerance 20%; Voltage *; MFR# SRP6540-4R7M
T16: 0395121002; Tolerance *; Voltage 300V; MFR# 0395121002
U4: AP63203WU-7; SOT-23-6_Handsoldering; Tolerance *; Voltage 32V, 3.3V; MFR# AP63203WU-7
U5: AP63205WU-7; SOT-23-6_Handsoldering; Tolerance *; Voltage 32V, 5V; MFR# AP63205WU-7

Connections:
+3V3: C20.1, C25.1, C27.1, L3.2, U4.1 (FB); also elsewhere on the board
+5V: C26.1, C28.1, C31.1, L4.2, U5.1 (FB); also elsewhere on the board
+24V: C19.1, C21.1, C22.1, D3.1, T16.1, U4.2 (EN), U4.3 (VIN), U5.2 (EN), U5.3 (VIN)
Earth: H1.1, H2.1, H3.1, H4.1
GND: C19.2, C20.2, C21.2, C22.2, C25.2, C26.2, C27.2, C28.2, C31.2, D3.2, T16.2, U4.4 (GND), U5.4 (GND); also elsewhere on the board
unnamed: C23.1, U4.6 (BST)
unnamed: C23.2, L3.1, U4.5 (SW)
unnamed: C24.1, U5.6 (BST)
unnamed: C24.2, L4.1, U5.5 (SW)

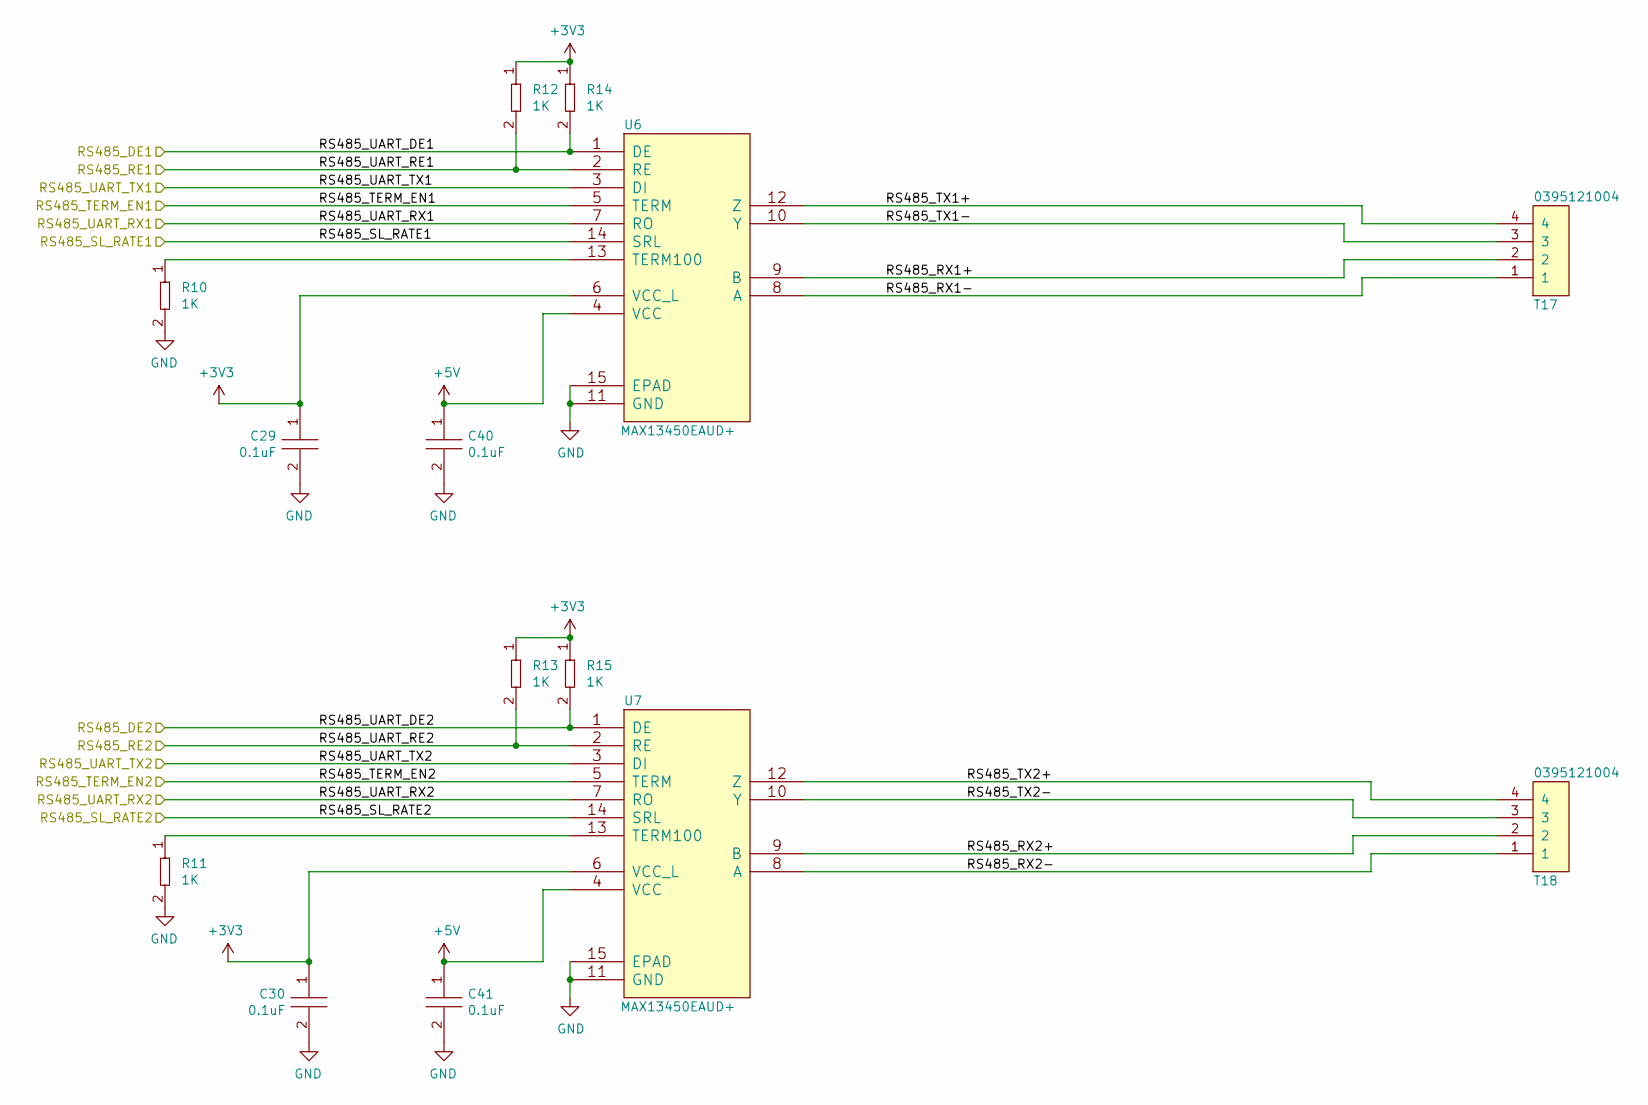
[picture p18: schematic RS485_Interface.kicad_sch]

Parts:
C29, C30: C0402C104K9PACTU; R0402; Tolerance 10%; Voltage 6.3V; MFR# C0402C104K9PACTU
C40, C41: CGA3E2X7R1H104K080AA; C0603; Tolerance 10%; Voltage 50V; MFR# CGA3E2X7R1H104K080AA
R10, R11, R12, R13, R14, R15: RC0402FR-071KL; R0402; Tolerance 1%; Voltage *; MFR# RC0402FR-071KL
T17, T18: 0395121004; Tolerance *; Voltage 300V; MFR# 0395121004
U6, U7: MAX13450EAUD+; MAX13450EAUD&plus_; Tolerance *; Voltage 4.75V ~ 5.25V; MFR# MAX13450EAUD+

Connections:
+3V3: C29.1, C30.1, R12.1, R13.1, R14.1, R15.1, U6.6 (VCC_L), U7.6 (VCC_L); also elsewhere on the board
+5V: C40.1, C41.1, U6.4 (VCC), U7.4 (VCC); also elsewhere on the board
/RS485 Interface/RS485_DE1: R14.2, U6.1 (DE); also elsewhere on the board
/RS485 Interface/RS485_DE2: R15.2, U7.1 (DE); also elsewhere on the board
/RS485 Interface/RS485_RE1: R12.2, U6.2 (RE); also elsewhere on the board
/RS485 Interface/RS485_RE2: R13.2, U7.2 (RE); also elsewhere on the board
/RS485 Interface/RS485_RX1+: T17.2, U6.9 (B)
/RS485 Interface/RS485_RX1-: T17.1, U6.8 (A)
/RS485 Interface/RS485_RX2+: T18.2, U7.9 (B)
/RS485 Interface/RS485_RX2-: T18.1, U7.8 (A)
/RS485 Interface/RS485_SL_RATE1: U6.14 (SRL); also elsewhere on the board
/RS485 Interface/RS485_SL_RATE2: U7.14 (SRL); also elsewhere on the board
/RS485 Interface/RS485_TERM_EN1: U6.5 (TERM); also elsewhere on the board
/RS485 Interface/RS485_TERM_EN2: U7.5 (TERM); also elsewhere on the board
/RS485 Interface/RS485_TX1+: T17.4, U6.12 (Z)
/RS485 Interface/RS485_TX1-: T17.3, U6.10 (Y)
/RS485 Interface/RS485_TX2+: T18.4, U7.12 (Z)
/RS485 Interface/RS485_TX2-: T18.3, U7.10 (Y)
/RS485 Interface/RS485_UART_RX1: U6.7 (RO); also elsewhere on the board
/RS485 Interface/RS485_UART_RX2: U7.7 (RO); also elsewhere on the board
/RS485 Interface/RS485_UART_TX1: U6.3 (DI); also elsewhere on the board
/RS485 Interface/RS485_UART_TX2: U7.3 (DI); also elsewhere on the board
GND: C29.2, C30.2, C40.2, C41.2, R10.2, R11.2, U6.11 (GND), U6.15 (EPAD), U7.11 (GND), U7.15 (EPAD); also elsewhere on the board
unnamed: R10.1, U6.13 (TERM100)
unnamed: R11.1, U7.13 (TERM100)

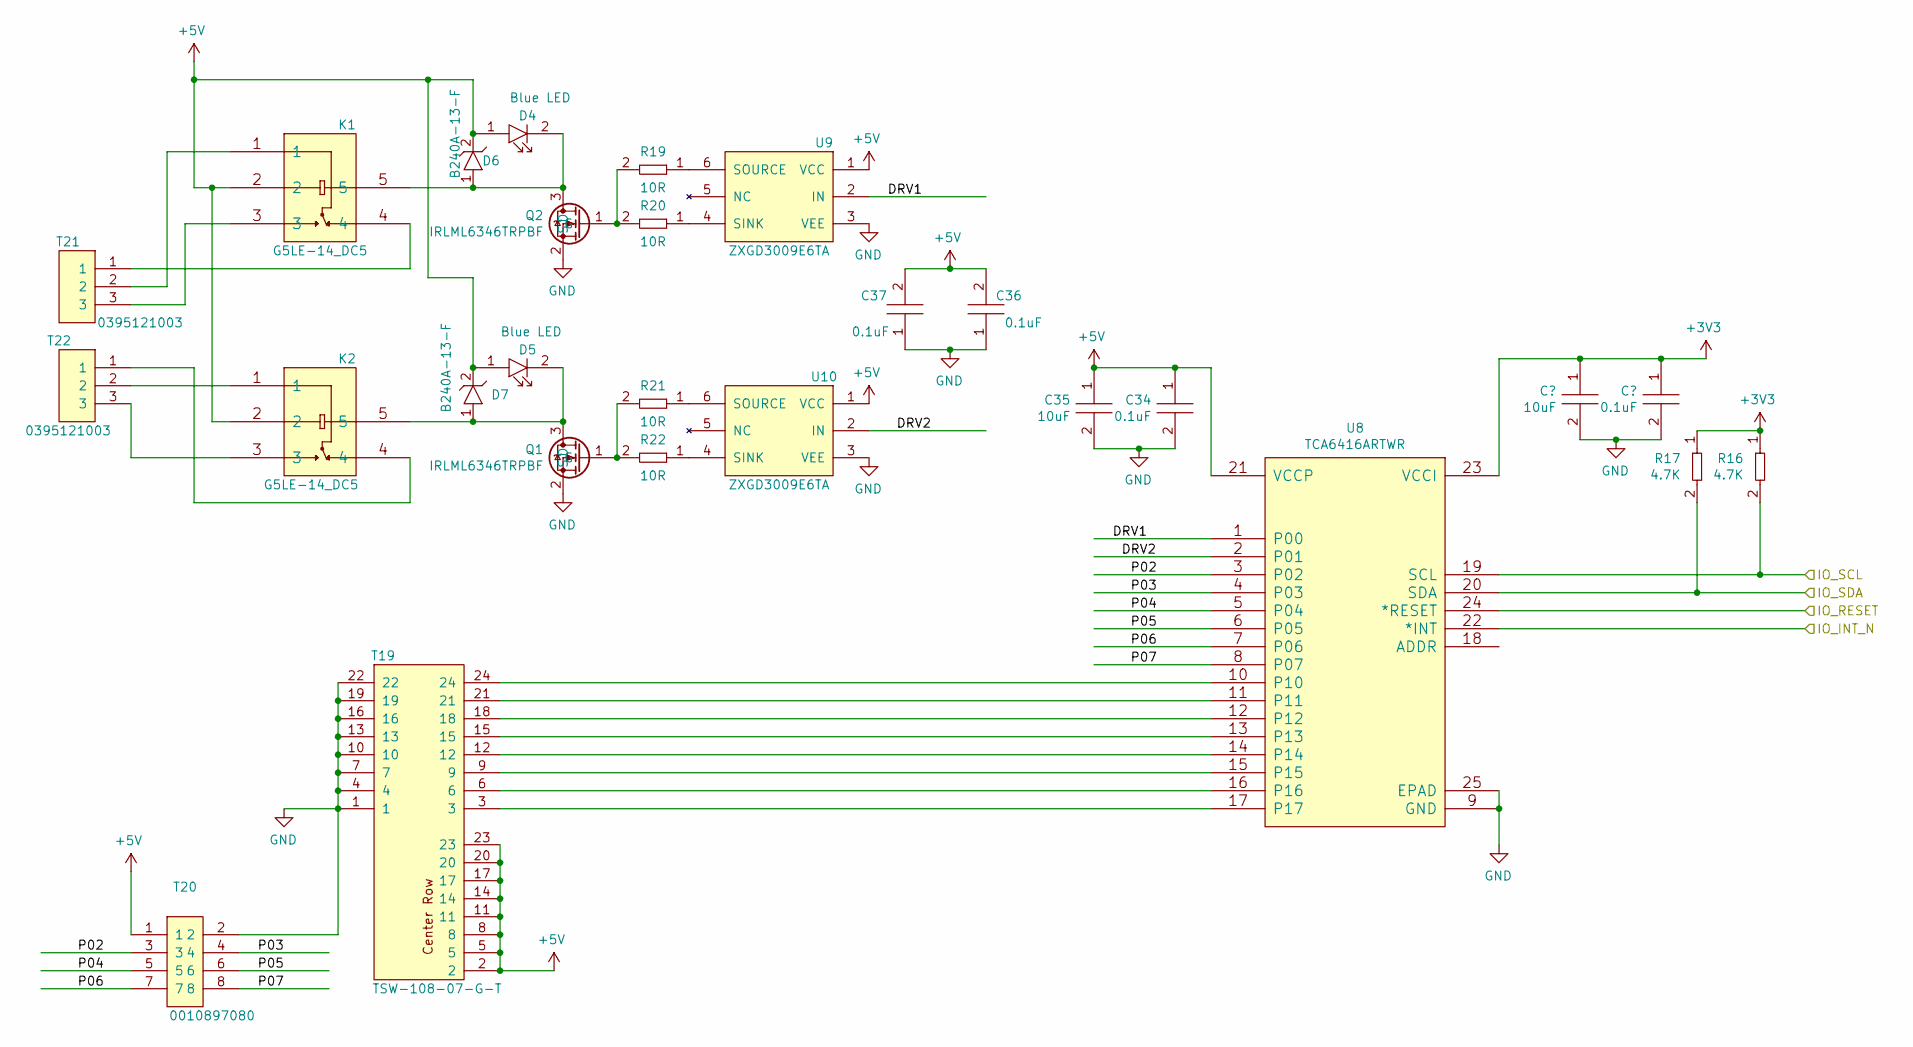
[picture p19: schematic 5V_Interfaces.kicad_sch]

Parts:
C32, C34, C36, C37: C0402C104K9PACTU; R0402; Tolerance 10%; Voltage 6.3V; MFR# C0402C104K9PACTU
C33, C35: GRM188R61A106KE69J; C0603; Tolerance 10%; Voltage 10V; MFR# GRM188R61A106KE69J
D4, D5: LTST-C194TBKT; LED0603; Tolerance *; Voltage 3.3V; MFR# LTST-C194TBKT
D6, D7: B240A-13-F; Tolerance *; Voltage 40V; MFR# B240A-13-F
K1, K2: G5LE-14_DC5; Tolerance *; Voltage 5VDC Coil, 250VAC, 125VDC - Max; MFR# G5LE-14 DC5
Q1, Q2: IRLML6346TRPBF; SOT-23; Tolerance *; Voltage 30V; MFR# IRLML6346TRPBF
R16, R17: RC0402FR-074K7L; R0402; Tolerance 1%; Voltage *; MFR# RC0402FR-074K7L
R19, R20, R21, R22: RC0402FR-0710RL; R0402; Tolerance 1%; Voltage *; MFR# RC0402FR-0710RL
T19: TSW-108-07-G-T; Tolerance *; Voltage *; MFR# TSW-108-07-G-T
T20: 0010897080; Pin_Header_Straight_2x04_Pitch2.54mm; Tolerance *; Voltage *; MFR# 0010897080
T21, T22: 0395121003; Tolerance *; Voltage 300V; MFR# 0395121003
U8: TCA6416ARTWR; Tolerance *; Voltage 1.65V ~ 5.5V; MFR# TCA6416ARTWR
U9, U10: ZXGD3009E6TA; SOT-23-6_Handsoldering; Tolerance *; Voltage 40V; MFR# ZXGD3009E6TA

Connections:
+3V3: C32.1, C33.1, R16.1, R17.1, U8.23 (VCCI); also elsewhere on the board
+5V: C34.1, C35.1, C36.2, C37.2, D4.1, D5.1, D6.2, D7.2, K1.2, K2.2, T19.2, T19.5, T19.8, T19.11, T19.14, T19.17, T19.20, T19.23, T20.1, U8.21 (VCCP), U9.1 (VCC), U10.1 (VCC); also elsewhere on the board
/5V IO Interfaces/DRV1: U8.1 (P00), U9.2 (IN)
/5V IO Interfaces/DRV2: U8.2 (P01), U10.2 (IN)
/5V IO Interfaces/IO_INT_N: U8.22 (*INT); also elsewhere on the board
/5V IO Interfaces/IO_RESET: U8.24 (*RESET); also elsewhere on the board
/5V IO Interfaces/IO_SCL: R16.2, U8.19 (SCL); also elsewhere on the board
/5V IO Interfaces/IO_SDA: R17.2, U8.20 (SDA); also elsewhere on the board
/5V IO Interfaces/P02: T20.3, U8.3 (P02)
/5V IO Interfaces/P03: T20.4, U8.4 (P03)
/5V IO Interfaces/P04: T20.5, U8.5 (P04)
/5V IO Interfaces/P05: T20.6, U8.6 (P05)
/5V IO Interfaces/P06: T20.7, U8.7 (P06)
/5V IO Interfaces/P07: T20.8, U8.8 (P07)
GND: C32.2, C33.2, C34.2, C35.2, C36.1, C37.1, Q1.2 (S), Q2.2 (S), T19.1, T19.4, T19.7, T19.10, T19.13, T19.16, T19.19, T19.22, T20.2, U8.9 (GND), U8.25 (EPAD), U9.3 (VEE), U10.3 (VEE); also elsewhere on the board
unnamed: D4.2, D6.1, K1.5, Q2.3 (D)
unnamed: D5.2, D7.1, K2.5, Q1.3 (D)
unnamed: K1.1, T21.2
unnamed: K1.3, T21.3
unnamed: K1.4, T21.1
unnamed: K2.1, T22.2
unnamed: K2.3, T22.3
unnamed: K2.4, T22.1
unnamed: Q1.1 (G), R21.2, R22.2
unnamed: Q2.1 (G), R19.2, R20.2
unnamed: R19.1, U9.6 (SOURCE)
unnamed: R20.1, U9.4 (SINK)
unnamed: R21.1, U10.6 (SOURCE)
unnamed: R22.1, U10.4 (SINK)
unnamed: T19.3, U8.17
unnamed: T19.6, U8.16
unnamed: T19.9, U8.15
unnamed: T19.12, U8.14
unnamed: T19.15, U8.13
unnamed: T19.18, U8.12
unnamed: T19.21, U8.11
unnamed: T19.24, U8.10

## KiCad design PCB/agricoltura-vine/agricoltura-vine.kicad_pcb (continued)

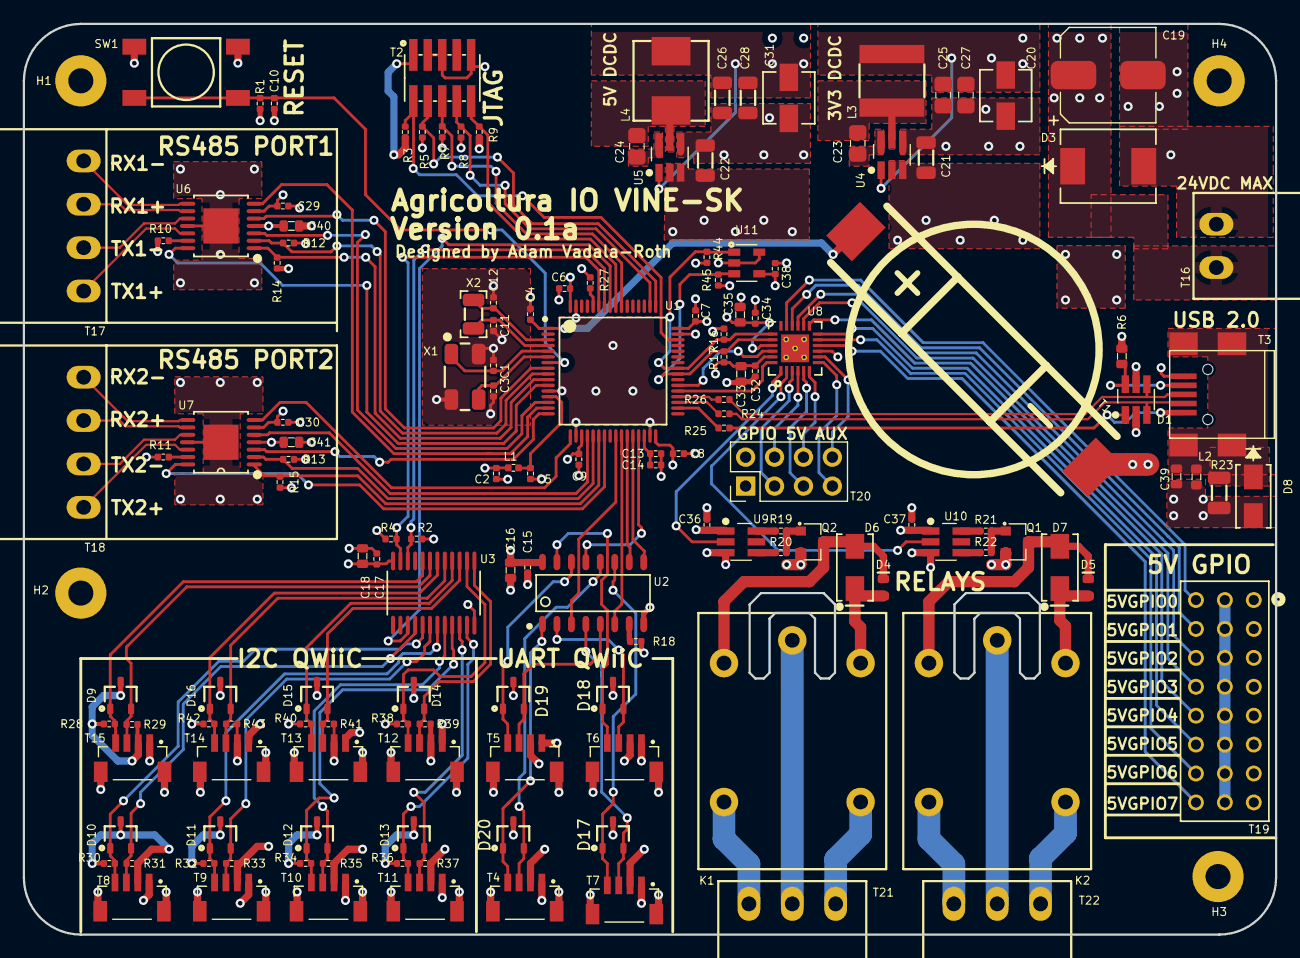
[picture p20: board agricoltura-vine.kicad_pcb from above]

Board: 4 copper layers, 110.0 x 80.0 mm, 153 parts (0 on the bottom side), 120 nets.

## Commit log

2020-06-17 Datasheets and Schematic
    started laying out the schematic, STM32 part copied from SunLeaf V2. Datasheets for components in use added to repo.
    [I2C_Interfaces.sch, Power.sch, RS485_Interface.sch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]
2020-06-17 Schematic process
    scheamtics laid out for all board subsyhstems, connecting MCU to subsystems still in progress, power yet to be designed.
    [I2C_Interfaces.sch, RS485_Interface.sch, STM32_MCU.sch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]
2020-06-18 Power Supplies
    designed power supplies for 3.3v and 5V as well as 24VAC input
    [Power.sch]
2020-06-18 5V Logic, Connector swap, and I2C refactor
    Added 5V IO logic, changed connectors over to grove style SMT, I2C refactored to use 8x mux instead fo two 4x mux.
    [5V_Interfaces.sch, I2C_Interfaces.sch, Power.sch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]
2020-06-18 Power supplies
    Both power supplies redsigned around new ICs for 2A of each voltage, since we have no idea how much current peripherals will be using.
    [Power.sch, STM32_MCU.sch]
2020-06-18 Schematic Pass 1
    All subsystem schematics are completed in their first pass, some features scaled back to make design more practical.
    [5V_Interfaces.sch, STM32_MCU.sch, UART_Interfaces.sch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]
2020-06-18 Schematic and Readme
    Readme updated with latest feature set, and schematic pages interconnected.
    [agricoltura-vine.sch]
2020-06-18 Board
    Board shape defined, though subject to change. Schematic anotated and parts exported to board.
    [5V_Interfaces.sch, I2C_Interfaces.sch, Power.sch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]
2020-06-19 Board Size , Connectors and Layout
    Changed board size and shape, started layout, swapped connectors over.
    [I2C_Interfaces.sch, Power.sch, Vine_Ivy_BRD_Margin.dxf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]
2020-06-20 Board shape and Rough PLacement
    Board shape adjusted to have smaller rounded corners increasing usable space of board shape. Finished rough placement of all the components, no routing yet. Debating connector style and form factor. 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
    [5V_Interfaces.sch, Power.sch, RS485_Interface.sch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]
2020-06-21 Route Started Connectors Changed
    Changed to QWIIC style connectors and adjusted pinning of RJ45s, but switching to screw terminal header in next commit. THis is a backup
    [5V_Interfaces.sch, I2C_Interfaces.sch, Power.sch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]
2020-06-22 Routing and New RS485
    swapped over the RS485 chip to a new one and started routing the board.
    [5V_Interfaces.sch, Power.sch, RS485_Interface.sch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]
2020-06-23 Routing progress
    RS845 ports routed, UART mux routed, sensor ports reoriented. Starting to come together.
    [STM32_MCU.sch, agricoltura-vine.kicad_pcb]
2020-06-23 Majopr Progress
    Board shape enlarged to simplify layout and accomodate larger size parts for sisterboard like Ivy. QWIIC connectors flipped to be correct, signals were oriented incorrectly in past revisions.
    [5V_Interfaces.sch, I2C_Interfaces.sch, STM32_MCU.sch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]
2020-06-24 IO Expander
    added IO expander for 5V IOs
    [5V_Interfaces.sch, Power.sch, agricoltura-vine.kicad_pcb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]
2020-06-27 Big Update
    Dropped 8 5V outputs in favor of two relays. Ditched microchip IO expander for a Ti one that does level conversion for outputs, eliminates Ti bidriectional converter and 74 line driver from design, s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
    [5V_Interfaces.sch, I2C_Interfaces.sch, STM32_MCU.sch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]
2020-06-29 Relay Driver Circuit, Board Size Change
    Added the Relay driver circuitry, increased size of board tobetter acccomodate relays, figuredout the powerplane topology to get 5Vs where it needs to go.
    [5V_Interfaces.sch, STM32_MCU.sch, UART_Interfaces.sch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]
2020-06-30 First pass of board
    Finished routing first pass of PCB
    [5V_Interfaces.sch, agricoltura-vine.kicad_pcb]
2020-06-30 Adjustments
    Moved Relays closer to edge, pushed VBAT battery holder back towards USB, optimized USB TVS circuit. Broke out extra 5V GPIOs to header
    [5V_Interfaces.sch]
2020-07-02 Netlabels and Datasheets
    Removed datasheets for parts no longer in design, added datasheet for RS485 transceiver. Added netlabels for RS485 signals.
    [RS485_Interface.sch, STM32_MCU.sch, agricoltura-vine.kicad_pcb]
2020-07-03 Connector Swap
    Switched over to dedicated connectors per relay
    [5V_Interfaces.sch, agricoltura-vine.kicad_pcb]
2020-07-20 EEPROM
    Added EEPROM chip to design, also beefed up USB grounding and shock protection
    [STM32_MCU.sch, agricoltura-vine.kicad_pcb]
2020-07-21 Added EEProm
    Eeprom added and routed in circuit board, USB resitors added. TVS diodes and pullups added to I2C ports not yet placed.
    [I2C_Interfaces.sch, STM32_MCU.sch, agricoltura-vine.kicad_pcb]
2020-07-29 Board tweaks
    TVS diodes added, board needs routing, a lot of board has been tweaked, more to come.
    [I2C_Interfaces.sch, STM32_MCU.sch, agricoltura-vine.kicad_pcb]
2020-08-09 TVS Diodes
    TVS diodes and pullups added to sensor connectors, implemented in schematic and board.
    [5V_Interfaces.sch, I2C_Interfaces.sch, UART_Interfaces.sch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]
2020-08-18 DC Power
    Power input section converted to 24VDC Max input instead of AC. A proper AC to DC power supply would need more components to be properly implmented and not require redesign of the DCDC regulators. Also the plan going forward is to be able to run thes off rechargeable battery packs as well as 24VDC bus voltages.
    [Power.sch, agricoltura-vine.kicad_pcb]
2024-03-26 Added license
    added license and updated kicad project
    [5V_Interfaces.kicad_sch, I2C_Interfaces.kicad_sch, Power.kicad_sch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]

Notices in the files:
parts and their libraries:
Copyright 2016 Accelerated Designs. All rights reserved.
